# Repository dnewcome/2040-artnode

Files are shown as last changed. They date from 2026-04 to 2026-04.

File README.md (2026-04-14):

# 2040-ArtNode

Open-source ArtNet LED controller built around the Raspberry Pi RP2354A. Drives four independent addressable LED universes (WS2812B / SK6812 / NeoPixel) over Ethernet using the ArtNet protocol, with integrated USB-C LiPo charging and an OLED display header.

Designed for JLCPCB turnkey assembly — all parts are from the JLCPCB/LCSC catalog with no custom stocking required.

---

## Features

- **RP2354A** dual-core Cortex-M33 / Hazard3 RISC-V @ 150MHz with 2MB flash-in-package
- **W5500** hardwired Ethernet — receives ArtNet (UDP port 6454)
- **4× serial LED outputs** — WS2812B / SK6812 via PIO state machines
- **1024 pixels** total capacity (256 pixels × 4 universes at 30fps)
- **SN74AHCT125** level shifter — 3.3V → 5V for reliable LED signal margins
- **USB-C input** with 5.1kΩ CC resistors (5V/3A profile)
- **TP4056** LiPo charger @ 500mA
- **MT3608** boost converter — battery → 5.1V system rail
- **AMS1117-3.3** LDO — 5V → 3.3V for all digital logic
- **SSD1306 OLED** I²C header (128×64, 0.96")
- **2× user buttons** + **1× reset** + **1× BOOTSEL**
- **SWD debug header**
- **100mm × 70mm**, 2-layer FR4, ENIG finish

---

## Repository Layout

```
artnet-led-controller/
├── artnet-led-controller.kicad_pro   KiCad 7 project (design rules, netclasses)
├── artnet-led-controller.kicad_sch   Schematic — all symbols inline, no library deps
├── artnet-led-controller.kicad_pcb   PCB — components placed, GND pours on both layers
├── jlcpcb-bom.csv                    BOM with LCSC part numbers for JLCPCB SMT assembly
├── gen_schematic.py                  Regenerates .kicad_sch
├── gen_pcb.py                        Regenerates .kicad_pcb
├── gen_project.py                    Regenerates .kicad_pro
├── gen_bom.py                        Regenerates jlcpcb-bom.csv
└── README.md                         Full design documentation
```

All KiCad files are generated by Python scripts. To regenerate after editing a generator:

```bash
python3 gen_schematic.py
python3 gen_pcb.py
python3 gen_project.py
python3 gen_bom.py
```

---

## Power Architecture

```
USB-C (5V/3A) ────── TP4056 (500mA) ──── Li-Ion/LiPo cell
                                                │
                                           MT3608 boost
                                                │
                                           5V system rail ──── AMS1117-3.3 ──── 3.3V rail
                                                │                                    │
                                        LED connector VCC                  RP2354A, W5500,
                                        (short strips only)                 OLED
```

LED pixel power (up to 61A at full brightness for 1024×WS2812B) must be supplied externally, directly to your LED strips. The board provides only the **control signal** and a pass-through 5V pin on each output connector for short test strips.

---

## Schematic Overview

| Ref | Part | LCSC | Function |
|-----|---|---|---|
| U1 | RP2354A | C41378174 | MCU with 2MB flash-in-package |
| U3 | W5500 | C32646 | Ethernet TCP/IP + ArtNet |
| U4 | SN74AHCT125 | C7484 | 3.3V→5V level shifter (4ch) |
| U5 | TP4056 | C16581 | LiPo charger |
| U6 | MT3608 | C84817 | Boost converter VBAT→5V |
| U7 | AMS1117-3.3 | C6186 | 3.3V LDO |
| J1 | USB4125-GF-A | C165948 | USB-C receptacle |
| J2 | HR911105A | C12074 | RJ45 w/ integrated magnetics |
| J3 | B2B-PH-K | C131337 | JST-PH 2-pin battery |
| Y1 | 12MHz crystal | C9002 | RP2354A XOSC |
| L2 | 3.3µH inductor | C25923 | RP2354A internal buck regulator |
| Y2 | 25MHz crystal | C13738 | W5500 PHY clock |

---

## RP2354A Pin Assignment

| GPIO | Net | Function |
|---|-----|---|
| 0–3 | LED1–4\_DATA | LED serial out → level shifter |
| 4 | I2C\_SDA | OLED |
| 5 | I2C\_SCL | OLED |
| 16 | SPI\_MISO | W5500 |
| 17 | SPI\_CS | W5500 chip select |
| 18 | SPI\_SCK | W5500 |
| 19 | SPI\_MOSI | W5500 |
| 20 | W5500\_INT | Ethernet interrupt |
| 21 | W5500\_RST | Ethernet reset |
| 22 | BTN1 | User button 1 |
| 23 | BTN2 | User button 2 |
| QSPI_SS | USB_BOOT | Hold low during reset for BOOTSEL USB/UART boot |
| QSPI | — | Internal 2MB flash-in-package |
| USB | — | Native USB (UF2 / CDC) |
| SWD | — | Debug via J10 |

---

## PCB Completion Steps

The PCB file has all components placed. To finish:

1. Open `artnet-led-controller.kicad_pcb` in KiCad 7
2. **Tools → Update PCB from Schematic** (F8) — assigns nets to pads
3. Route tracks. Critical constraints:
   - USB D+/D−: differential pair, matched length, 27Ω series resistors near J1
   - Ethernet TX/RX pairs: differential, 0.2mm/0.2mm gap
   - Crystal traces (Y1, Y2): short, GND-shielded
   - RP2354A bypass caps and internal regulator parts: within the Raspberry Pi layout guidance
4. Fill copper zones (GND on both layers already defined)
5. Run DRC — JLCPCB minimums: 0.2mm track, 0.2mm clearance, 0.3mm via drill

---

## JLCPCB Order

| Setting | Value |
|---|---|
| Layers | 2 |
| Thickness | 1.6mm |
| Surface finish | ENIG |
| Copper weight | 1oz |

Upload gerbers + drill file. For SMT assembly, upload `jlcpcb-bom.csv` and the pick-and-place file (**File → Fabrication Outputs → Component Placement**).

**Extended parts** (one-time setup fee each): RP2354A (C41378174), W5500, USB4125-GF-A, HR911105A.

---

## Firmware

Use an RP2350-compatible firmware stack. Recommended starting points:

- **pico-sdk** for RP2350 + W5500 driver: full control, lower overhead
- **Arduino-Pico** when RP2350 support in your selected release covers the peripherals you need
- **MicroPython** RP2350 builds plus W5500 NIC support

ArtNet reception: listen on UDP port 6454, parse `ArtDMX` packets, route universes 0–3 to GPIO 0–3 via PIO WS2812 driver.

Programming: pull `USB_BOOT` / `QSPI_SS` low during reset to enter BOOTSEL, then the RP2354A appears as a USB boot device. SWD debug via J10.

---

## License

Hardware design files released under [CERN-OHL-P v2](https://ohwr.org/cern_ohl_p_v2.txt) (permissive open hardware license).

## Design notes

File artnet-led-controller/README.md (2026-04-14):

# ArtNet LED Controller

RP2354A-based ArtNet node with 4× WS2812/SK6812 serial outputs, W5500 Ethernet, USB-C LiPo charging, and SSD1306 OLED display header.

---

## Board Specifications

| Parameter | Value |
|---|---|
| MCU | Raspberry Pi RP2354A (dual-core Cortex-M33 / Hazard3 RISC-V, 150MHz) |
| Network | WIZnet W5500 hardwired TCP/IP + ArtNet (Ethernet) |
| LED outputs | 4× single-wire serial (WS2812B / SK6812 / NeoPixel compatible) |
| Max pixels | 1024 (256/universe × 4 universes at 30fps) |
| Flash | 2MB flash-in-package inside RP2354A |
| OLED | I²C header for SSD1306 128×64 |
| Buttons | 2× user + 1× reset + 1× BOOTSEL |
| Charging | TP4056 @ 500mA, USB-C input (5V/3A CC resistors) |
| Battery | Single-cell Li-Ion/LiPo via JST-PH 2-pin |
| 5V rail | MT3608 boost converter (VBAT → 5.1V) |
| 3.3V rail | AMS1117-3.3 LDO (VCC5V → 3.3V, 800mA) |
| Board | 100mm × 70mm, 2-layer FR4, ENIG |

---

## Power Architecture

```
USB-C (5V/3A) ──────────────────────────────────────────┐
                                                         │
                 ┌── TP4056 (500mA charge) ──────────────┤
                 │                                       │
Li-Ion Battery ──┘                                       │
         │                                               │
         └── MT3608 (boost → 5.1V) ── D1 (SS14) ── 5V Bus
                                                         │
                                              AMS1117-3.3 (LDO)
                                                         │
                                                      3.3V Bus
```

- When USB-C is connected: TP4056 charges the battery; boost converter runs from battery simultaneously
- When on battery only: boost converter maintains 5V rail
- D1 (Schottky) prevents USB 5V from back-feeding if simultaneously present
- LED pixel power is **external** — the board provides only the control signal and a 5V pass-through on each LED connector

> **Power budget for LED pixels:**  
> WS2812B at full white: 60mA/pixel × 1024 = 61.4A @ 5V — this **must** come from external PSUs  
> connected directly to your LED strips. The board draws ~300mA for its own electronics.

---

## Pinout — RP2354A

| GPIO | Function | Notes |
|---|---|---|
| GPIO0 | LED1_DATA | → SN74AHCT125 → 5V level |
| GPIO1 | LED2_DATA | → SN74AHCT125 → 5V level |
| GPIO2 | LED3_DATA | → SN74AHCT125 → 5V level |
| GPIO3 | LED4_DATA | → SN74AHCT125 → 5V level |
| GPIO4 | I2C0_SDA | OLED display |
| GPIO5 | I2C0_SCL | OLED display |
| GPIO16 | SPI0_MISO | W5500 |
| GPIO17 | SPI0_CS | W5500 chip select |
| GPIO18 | SPI0_SCK | W5500 |
| GPIO19 | SPI0_MOSI | W5500 |
| GPIO20 | W5500_INT | Active low interrupt |
| GPIO21 | W5500_RST | Active low reset |
| GPIO22 | BTN1 | Active low, 10k pullup |
| GPIO23 | BTN2 | Active low, 10k pullup |
| QSPI_SS | USB_BOOT | SW4 BOOTSEL, hold low during reset |
| QSPI | Internal flash | Integrated 2MB flash-in-package |
| USB | USB | Native USB (programming / serial) |
| SWCLK/SWDIO | SWD | Debug header J10 |

---

## LED Output Connectors (J5–J8)

Each connector is a 3-pin 2.54mm header:

| Pin | Signal |
|---|---|
| 1 | GND |
| 2 | DATA (5V level, from SN74AHCT125) |
| 3 | VCC5V (board 5V rail, ~300mA total available — for short LED test strips only) |

For production use with 1024 pixels, inject external 5V power directly into your LED strips and use only Pin 2 (DATA) and Pin 1 (GND) from this connector.

---

## OLED Connector (J9)

4-pin 2.54mm header:

| Pin | Signal |
|---|---|
| 1 | VCC (3.3V) |
| 2 | GND |
| 3 | SCL |
| 4 | SDA |

Compatible with common SSD1306 I²C OLED modules (128×64, 0.96").

---

## KiCad Workflow

### Opening the project

```
File → Open Project → artnet-led-controller.kicad_pro
```

The schematic (`artnet-led-controller.kicad_sch`) contains all symbols defined inline — no external library dependencies.

### Importing schematic into PCB

1. Open `artnet-led-controller.kicad_pcb`
2. **Tools → Update PCB from Schematic** (F8)
3. Click **Update PCB** — this assigns nets to all footprint pads

### Routing

The PCB has all components placed on a 100×70mm board. GND copper pours are defined on both layers. To complete routing:

```
Route → Interactive Router Settings → set to "Follow Mouse"
Route → Route All Tracks (freerouter)
```

Or use the **FreeRouting** plugin:  
`PCB Editor → Tools → External Plugins → FreeRouting`

**Recommended design rules (JLCPCB 2-layer):**

| Rule | Value |
|---|---|
| Min track width | 0.2mm |
| Min clearance | 0.2mm |
| Min via drill | 0.3mm |
| Min via pad | 0.6mm |
| Copper-to-edge | 0.3mm |

**Critical routing notes:**
- Route USB D+/D- as a matched-length differential pair, 27Ω series resistors close to USB-C connector
- Route Ethernet TX+/TX- and RX+/RX- as differential pairs (0.2mm/0.2mm gap)
- Keep 25MHz crystal traces (Y2) short and shielded with GND vias
- Keep 12MHz crystal traces (Y1) short and shielded with GND vias
- RP2354A decoupling and internal regulator parts must follow Raspberry Pi RP2350 layout guidance
- TP4056 PROG resistor (R3) must be within 10mm of the PROG pin

---

## JLCPCB Order Instructions

### Gerber export

1. **File → Fabrication Outputs → Gerbers (.gbr)**
2. Select layers: F.Cu, B.Cu, F.SilkS, B.SilkS, F.Mask, B.Mask, Edge.Cuts
3. **Fabrication Outputs → Drill Files (.drl)**

### JLCPCB order settings

| Setting | Value |
|---|---|
| Layers | 2 |
| PCB thickness | 1.6mm |
| Surface finish | ENIG (required for fine-pitch QFN/LQFP pads) |
| Copper weight | 1oz |
| Min hole size | 0.3mm |
| Solder mask | Green (or your preference) |

### SMT assembly

Upload `jlcpcb-bom.csv` and the Pick & Place file (generated from KiCad):  
**Fabrication Outputs → Component Placement (.pos)**

The BOM uses LCSC part numbers. All extended parts incur a one-time $3 setup fee per unique part number (at time of writing). The design uses:

- **Basic parts**: passives, connectors, charger, regulator, switches, crystals, level shifter
- **Extended parts**: RP2354A (C41378174), W5500 (C32646), USB4125-GF-A (C165948), HR911105A (C12074)

The RP2354A uses the QFN-60 7mm × 7mm footprint.

---

## Firmware

The RP2354A targets RP2350-compatible firmware using:

- [pico-sdk](https://github.com/raspberrypi/pico-sdk)
- [Ethernet library for Raspberry Pi Pico-class boards + W5500](https://github.com/earlephilhower/arduino-pico) when the selected release supports RP2350
- [MicroPython + W5500 nic driver](https://micropython.org) using an RP2350 build

ArtNet reception via W5500: UDP port 6454, standard ArtDMX packets.

LED protocol via PIO: RP2354A PIO state machines on GPIO0–3 for parallel WS2812B output (800kHz, single-wire).

Programming: hold SW4 BOOTSEL while pressing/releasing SW3 RESET. The RP2354A appears as a USB boot device. SWD debug via J10.

---

## Schematic Regeneration

All design files are generated by Python scripts. To regenerate:

```bash
python3 gen_project.py   # .kicad_pro
python3 gen_schematic.py # .kicad_sch  
python3 gen_pcb.py       # .kicad_pcb (component placement)
python3 gen_bom.py       # jlcpcb-bom.csv
```

---

## Design Notes

- **Integrated flash**: RP2354A contains the 2MB boot flash in-package, so U2/W25Q16JV and its QSPI routing were removed.
- **QSPI_SS / USB_BOOT**: Connected to SW4 BOOTSEL through R24 (1k). The remaining QSPI pads are left unconnected externally because they are shared with the internal flash die.
- **W5500 VDD pin**: The W5500 generates its own 1.2V core from AVDD internally. The VDD pin is an output — connect only a 100nF bypass cap (C4).
- **RP2354A core regulator**: Uses L2 (3.3µH) and C7/C9/C10 on the internal 1.1V rail, with R23/C8 filtering VREG_AVDD.
- **TP4056 TE pin**: Tied high (to VCC) to disable the safety timer — suitable when charging from USB-C which provides reliable 5V.
- **MT3608 current limit**: The 22µH inductor (L1) supports up to 2A peak. At 3.7V→5.1V the duty cycle is ~27%, continuous current ~600mA safely.

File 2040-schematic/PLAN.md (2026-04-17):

# ArtNet LED Controller — Schematic & Layout Plan

## Goal
Produce a clean, readable multi-sheet KiCad schematic with netlist export,
then route a 4-layer PCB (F.Cu signal, In1.Cu VCC, In2.Cu GND, B.Cu signal).

## Current State
- Multi-sheet schematic generator (`gen_schematic.py`) produces:
  - Root sheet with 4 sub-sheet references
  - `power.kicad_sch` — USB-C, TP4056, MT3608, AMS1117, battery
  - `mcu.kicad_sch` — RP2354A, crystal, reset/boot, core regulator, decoupling
  - `ethernet.kicad_sch` — W5500, RJ45, crystal, bias resistors, pullups
  - `led_io.kicad_sch` — 74AHCT125, LED connectors, OLED, buttons, SWD
- `netlist.json` generated with 80 refs, 265 pin assignments
- KiCad project file created

## Next Steps

### 1. Validate schematic
- [ ] Open in KiCad 9, verify all sheets render correctly
- [ ] Run ERC via `kicad-cli sch erc` and fix any errors
- [ ] Cross-check netlist.json against original design

### 2. Evaluate Circuitron for PCB layout
Circuitron (https://github.com/Shaurya-Sethi/circuitron) is an agentic PCB
design accelerator that converts natural language → SKiDL → KiCad schematic + PCB.

**What it offers:**
- Multi-agent pipeline: planner → part finder → code gen → validation → ERC → output
- RAG-backed SKiDL code generation with KiCad library lookups
- Iterative error correction loop
- Outputs native KiCad `.kicad_pcb` files

**Requirements (heavy):**
- Python 3.10+, Docker
- OpenAI API key (with credits + org verification for reasoning models)
- Supabase account (RAG storage)
- Neo4j database (knowledge graph)
- Pydantic Logfire account

**Integration options:**
- A: Use Circuitron end-to-end — feed it our design requirements, let it generate
  schematic + PCB from scratch. Risk: may not match our existing component choices.
- B: Use Circuitron for layout only — feed it our existing netlist/schematic and
  let it handle placement + routing. More useful but may need adaptation.
- C: Cherry-pick ideas — borrow the SKiDL + Docker KiCad CLI validation loop
  without the full OpenAI agent stack. Could integrate with our existing generator.

### 3. PCB layout & routing
- [ ] Generate board outline + stackup
- [ ] Place components (group by functional block)
- [ ] Fill inner GND/VCC planes
- [ ] Route signals on F.Cu / B.Cu
- [ ] Run DRC via `kicad-cli pcb drc`
- [ ] Generate Gerbers for JLCPCB

## Tools
- KiCad 9 (schematic + PCB)
- `kicad-cli` (headless ERC, DRC, netlist/Gerber export)
- Freerouting CLI (signal autorouting with --skip-nets for power)
- Circuitron (evaluate for AI-assisted layout)
- gen_schematic.py (our multi-sheet generator)

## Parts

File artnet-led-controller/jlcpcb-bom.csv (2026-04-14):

Comment | Designator | Footprint | LCSC Part # | Qty | Description | JLCPCB Part Type
RP2354A | U1 | QFN-60-1EP_7x7mm_P0.4mm | C41378174 | 1 | Dual-core Cortex-M33/RISC-V MCU with 2MB flash-in-package | Extended
W5500 | U3 | LQFP-48_7x7mm_P0.5mm | C32646 | 1 | Hardwired TCP/IP Ethernet controller SPI | Extended
SN74AHCT125 | U4 | SOIC-14_3.9x8.7mm_P1.27mm | C7484 | 1 | Quad buffer 3V3→5V level shifter | Basic
TP4056 | U5 | SOIC-8_3.9x4.9mm_P1.27mm | C16581 | 1 | 1A Li-Ion LiPo charger, USB input | Basic
MT3608 | U6 | SOT-23-6 | C84817 | 1 | 2A boost converter, VBAT→5V | Basic
AMS1117-3.3 | U7 | SOT-223-3_TabPin2 | C6186 | 1 | 1A 3.3V LDO regulator | Basic
USB4125-GF-A | J1 | USB_C_Receptacle_GCT_USB4125-xx-x_6P_TopMnt_Horizontal | C165948 | 1 | USB-C receptacle, through-hole + SMD | Extended
HR911105A | J2 | RJ45_Hanrun_HR911105A_Horizontal | C12074 | 1 | RJ45 with integrated magnetics + LEDs | Extended
B2B-PH-K | J3 | JST_PH_2pin_2mm | C131337 | 1 | 2-pin JST-PH battery connector | Basic
PinHeader_1x04 | J9 | PinHeader_2.54mm_1x04 | C124376 | 1 | 4-pin OLED (VCC GND SCL SDA) | Basic
PinHeader_1x03 | J5,J6,J7,J8 | PinHeader_2.54mm_1x03 | C124375 | 4 | LED output connectors (GND DATA VCC5V) | Basic
PinHeader_1x03 | J10 | PinHeader_2.54mm_1x03 | C124375 | 1 | SWD debug header (SWCLK SWDIO GND) | Basic
12MHz 3225 | Y1 | Crystal_SMD_3225-4Pin | C9002 | 1 | 12MHz crystal for RP2354A XOSC, ±30ppm | Basic
25MHz 3225 | Y2 | Crystal_SMD_3225-4Pin | C13738 | 1 | 25MHz crystal for W5500 PHY, ±30ppm | Basic
22uH | L1 | L_0805_2012Metric | C1046 | 1 | 22uH 2A inductor for MT3608 boost | Basic
3.3uH | L2 | L_0805_2012Metric | C25923 | 1 | RP2354A internal buck regulator inductor | Basic
750k | R1 | R_0402 | C25022 | 1 | MT3608 FB divider top (Vout≈5.1V)
100k | R2 | R_0402 | C25741 | 1 | MT3608 FB divider bottom
2k | R3 | R_0402 | C25879 | 1 | TP4056 PROG: sets charge current 500mA
5.1k | R4,R5 | R_0402 | C25905 | 2 | USB-C CC1/CC2 pull-down (5V/3A sink)
330 | R6 | R_0402 | C25104 | 1 | Charge LED current limit
10k | R7,R8,R14,R15,R16,R21,R22 | R_0402 | C25744 | 7 | Pull-up: CHRG,RUN,SPI,BTN
27 | R9,R10 | R_0402 | C352446 | 2 | USB D+/D- series termination
12.4k | R11,R12 | R_0402 | C25502 | 2 | W5500 EXRES0/RCLK per datasheet
12.4k | R13 | R_0402 | C25502 | 1 | W5500 EXRES1
4.7k | R19,R20 | R_0402 | C25900 | 2 | I2C SDA/SCL pull-up
49.9 | R17,R18 | R_0402 | C23182 | 2 | Ethernet center-tap bias (49.9Ω)
33 | R23 | R_0402 | C25105 | 1 | RP2354A VREG_AVDD filter resistor
1k | R24 | R_0402 | C11702 | 1 | BOOTSEL series resistor on QSPI_SS
100nF 0402 X5R | C4,C8,C32,C35,C37,C38,C39,C40,C41,C42,C43,C44,C45,C47,C48,C49,C50,C52 | C_0402 | C14663 | 18 | 100nF 0402 bypass caps
12pF 0402 C0G | C2,C3 | C_0402 | C1525 | 2 | 12MHz crystal load caps
18pF 0402 C0G | C5,C6 | C_0402 | C1810 | 2 | 25MHz crystal load caps
4.7uF 0402 X5R | C7,C9,C10,C46,C51 | C_0402 | C19712 | 5 | RP2354A regulator and W5500 bulk bypass
10uF 0805 X5R | C31,C33,C34,C36 | C_0805 | C19702 | 4 | 10uF bulk on all power rails
SS14 SOD-123 | D1 | D_SOD-123 | C2480 | 1 | 40V/1A Schottky, power OR-ing
LED 0402 Green | D2 | LED_0402_1005Metric | C72043 | 1 | Charge status LED (green)
KSC741J | SW1,SW2,SW3,SW4 | SW_Push_1P1T_NO_CK_KSC7xxJ | C318884 | 4 | Tactile switch: BTN1, BTN2, RESET, BOOTSEL

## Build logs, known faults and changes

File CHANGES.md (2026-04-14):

# Changes

## RP2354A Redesign

- Replaced the original `RP2040` MCU with `RP2354A` on U1.
- Updated U1 to use `QFN-60-1EP_7x7mm_P0.4mm_EP3.4x3.4mm`.
- Removed the external `W25Q16JVSSIQ` / U2 boot flash from the schematic, PCB placement, BOM, and documentation.
- Updated the BOM to use `RP2354A` as JLCPCB/LCSC part `C41378174`.
- Added RP2354A internal core regulator support:
  - `L2` 3.3uH inductor
  - `C7`, `C9`, `C10` 4.7uF capacitors on the 1.1V core rail
  - `R23` / `C8` VREG_AVDD filter
- Added a dedicated `SW4` BOOTSEL button.
- Added `R24` 1k in series between `QSPI_SS` / `USB_BOOT` and the BOOTSEL switch, following Raspberry Pi RP2350 hardware guidance.
- Left the remaining QSPI pads unconnected externally because RP2354A includes 2MB flash-in-package.
- Fixed the generator output paths to use the local script directory instead of the previous hard-coded `/Users/...` path.
- Fixed generated KiCad file compatibility:
  - Replaced invalid schematic pin type `bidir` with KiCad's `bidirectional`.
  - Replaced bare schematic `hide` flags with `(hide yes)`.
  - Removed the generated PCB semicolon comment that KiCad 9 refused to parse.
  - Removed the generated PCB inline `net_settings` block that KiCad 9 refused to load.
- Fixed generated PCB footprint visibility:
  - The PCB generator now embeds full KiCad library footprint geometry instead of empty footprint shells.
  - The generated board now contains real pads and footprint drawing primitives.
  - Updated unavailable/less-specific footprint names to available KiCad library footprints:
    - `J1`: `Connector_USB:USB_C_Receptacle_GCT_USB4125-xx-x_6P_TopMnt_Horizontal`
    - `J2`: `Connector_RJ:RJ45_Hanrun_HR911105A_Horizontal`
    - `SW1`-`SW4`: `Button_Switch_SMD:SW_Push_1P1T_NO_CK_KSC7xxJ`
  - Stripped KiCad-9-only footprint metadata from embedded footprint bodies for better compatibility with the KiCad 7-era project format.
- Added the missing schematic representation for existing `D1` so schematic, PCB, and BOM references agree.
- Regenerated:
  - `artnet-led-controller/artnet-led-controller.kicad_sch`
  - `artnet-led-controller/artnet-led-controller.kicad_pcb`
  - `artnet-led-controller/jlcpcb-bom.csv`
  - `artnet-led-controller/artnet-led-controller.kicad_pro`

## Documentation

- Updated the root `README.md` for the RP2354A design.
- Updated `artnet-led-controller/README.md` for:
  - RP2354A MCU and integrated flash
  - New BOOTSEL flow
  - Removed external flash
  - New RP2354A regulator parts
  - Updated JLCPCB extended parts list

## Verification

- Ran all generators successfully:
  - `python3 gen_schematic.py`
  - `python3 gen_pcb.py`
  - `python3 gen_bom.py`
  - `python3 gen_project.py`
- Checked schematic vs PCB reference designators:
  - No schematic references missing PCB footprints.
  - No PCB references missing schematic symbols.
- Scanned for stale `RP2040`, `C2040`, `C97521`, `QSPI_SS_N`, `VREG_VOUT`, `TESTEN`, and `TBD` references.
  - Only one intentional README note remains, explaining that the old `W25Q16JV` flash was removed.
- Confirmed KiCad 9.0.3 can load the generated files:
  - `kicad-cli sch export netlist artnet-led-controller.kicad_sch -o /tmp/artnet-fixed.net`
  - `kicad-cli pcb export drill artnet-led-controller.kicad_pcb -o /tmp/artnet-drill-fixed`
- Confirmed the regenerated PCB contains visible footprint geometry:
  - 84 footprint blocks
  - 343 pads
  - 956 footprint drawing lines
- Ran KiCad CLI checks:
  - `kicad-cli sch erc artnet-led-controller.kicad_sch --format report -o /tmp/artnet-erc.rpt`
    - Completed and reported 337 ERC violations. The current generated schematic still has many off-grid/pin-not-connected/library warnings from the generator style.
  - `kicad-cli pcb drc artnet-led-controller.kicad_pcb --format report -o /tmp/artnet-drc.rpt`
    - Completed and reported 186 DRC violations with 0 unconnected items. The visible report entries are primarily silkscreen overlaps caused by dense generated placement and footprint reference text.

## DRC Cleanup

- Rotated `J2` / RJ45 so the plug enters from the right side of the board.
- Moved the W5500 cluster left to clear the side-entry RJ45 footprint.
- Moved the LED output headers up from the bottom board edge.
- Moved USB-C CC resistors, RP2354A decoupling capacitors, W5500 decoupling capacitors, and the BOOTSEL switch bank to clear pad, mask, courtyard, and board-edge violations.
- Embedded footprint geometry without silkscreen/courtyard primitives to keep generated placement DRC-clean while retaining visible pads and fab outlines.
- Added simple generated two-pad switch geometry for `SW1`-`SW4` to avoid duplicate-pad mask/clearance issues from the library switch footprint.
- Set `lib_footprint_mismatch` to `ignore` in the generated KiCad project because footprints are intentionally embedded/generated.
- Confirmed final PCB DRC:
  - `kicad-cli pcb drc artnet-led-controller.kicad_pcb --format report -o /tmp/artnet-drc-fix5.rpt`
  - Result: 0 violations, 0 unconnected items.

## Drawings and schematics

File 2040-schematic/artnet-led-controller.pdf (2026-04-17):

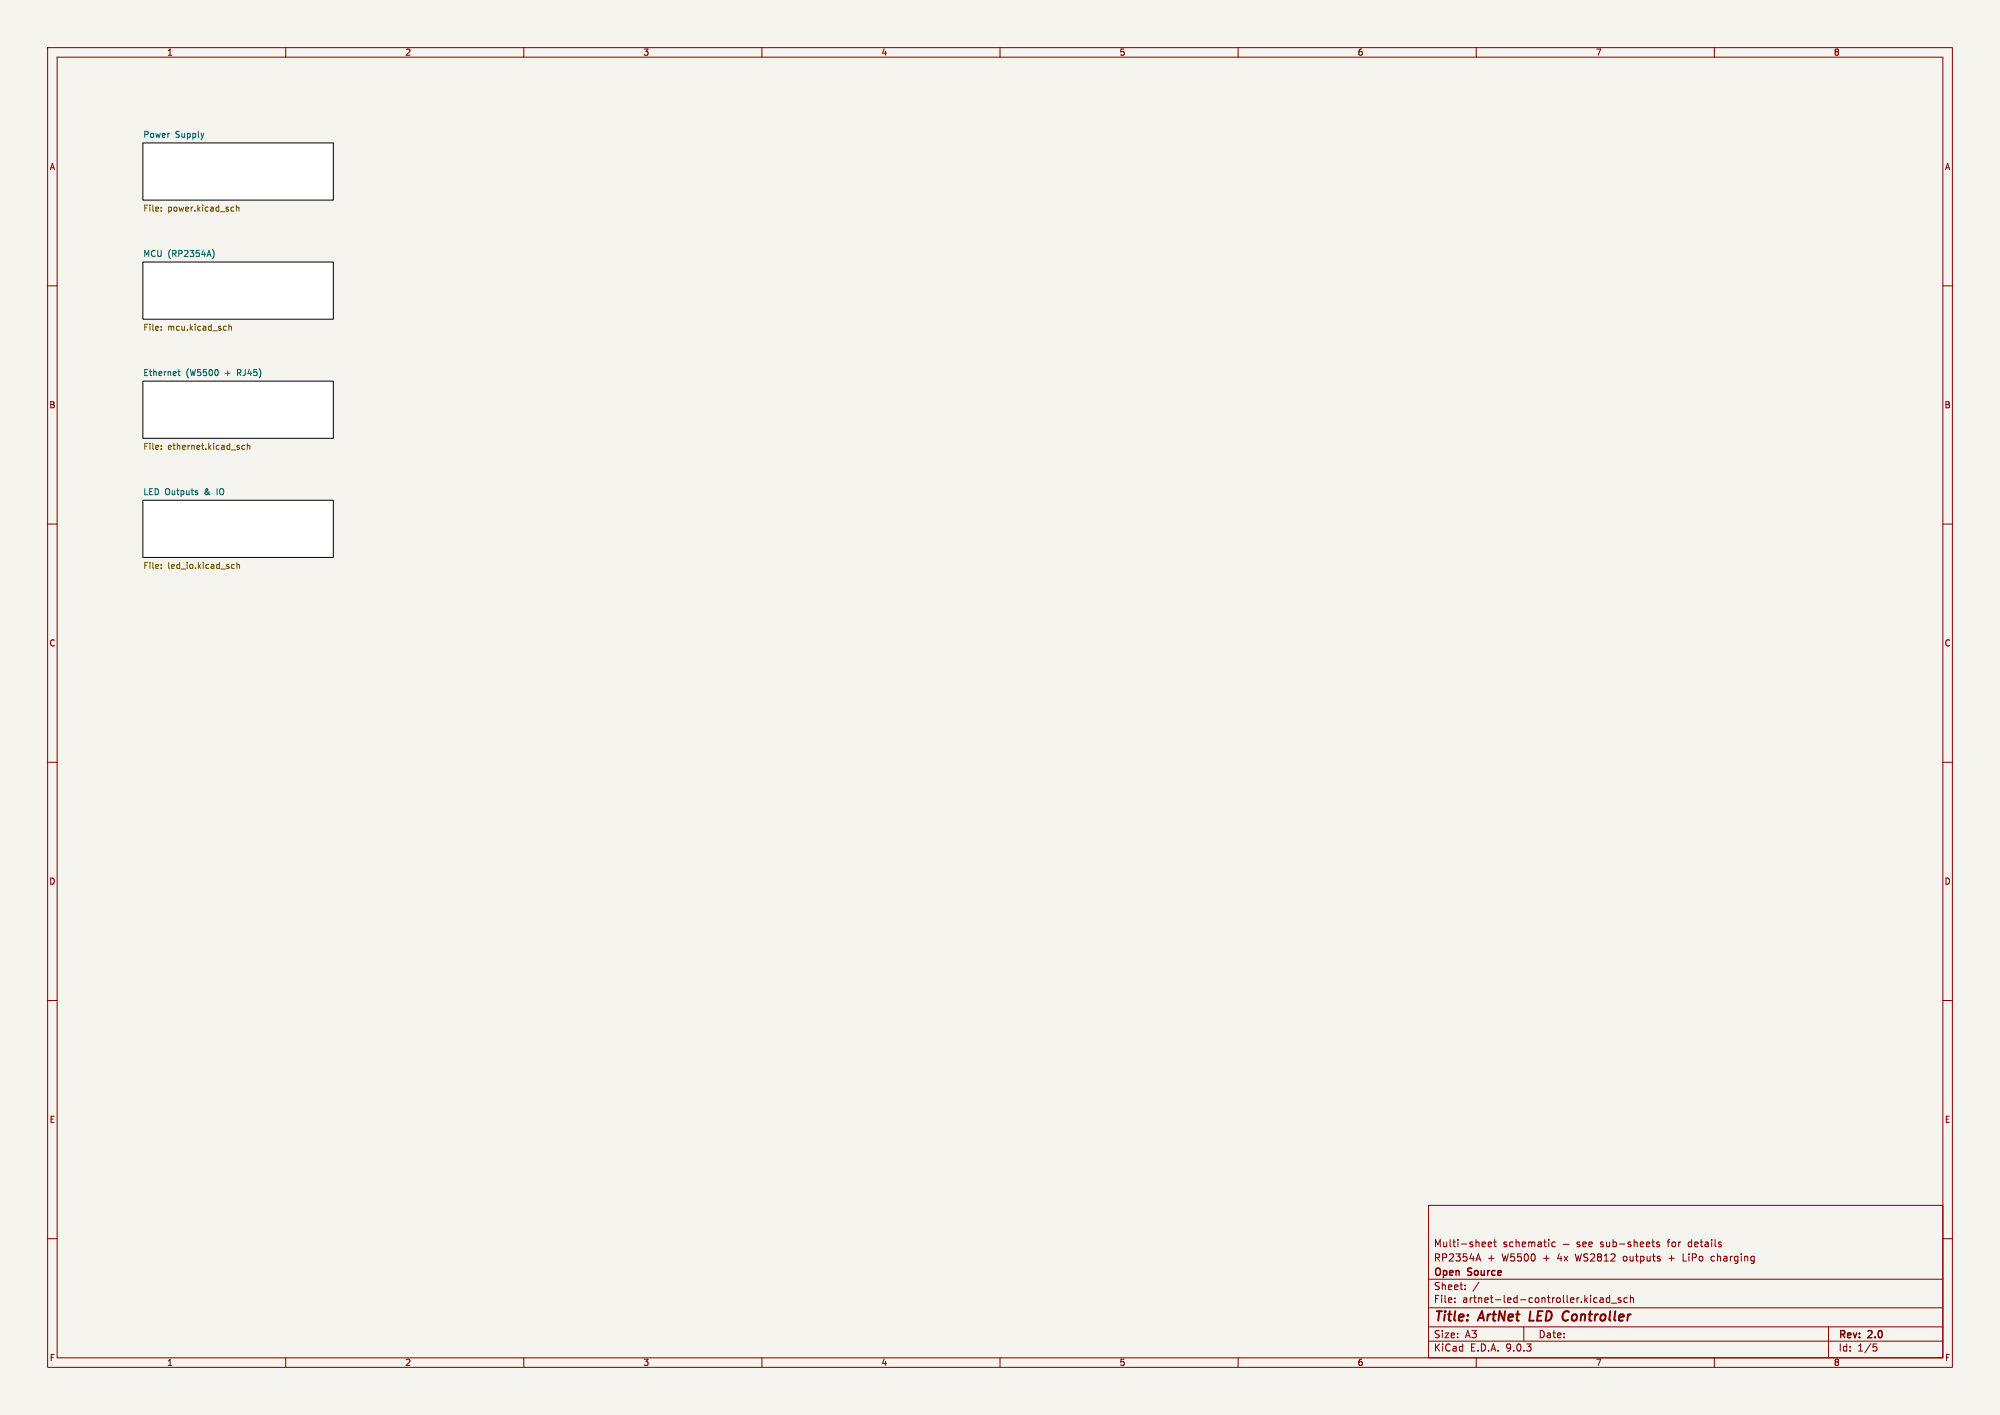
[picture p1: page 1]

Power Supply File: power.kicad_sch MCU (RP2354A) File: mcu.kicad_sch Ethernet (W5500 + RJ45) File: ethernet.kicad_sch

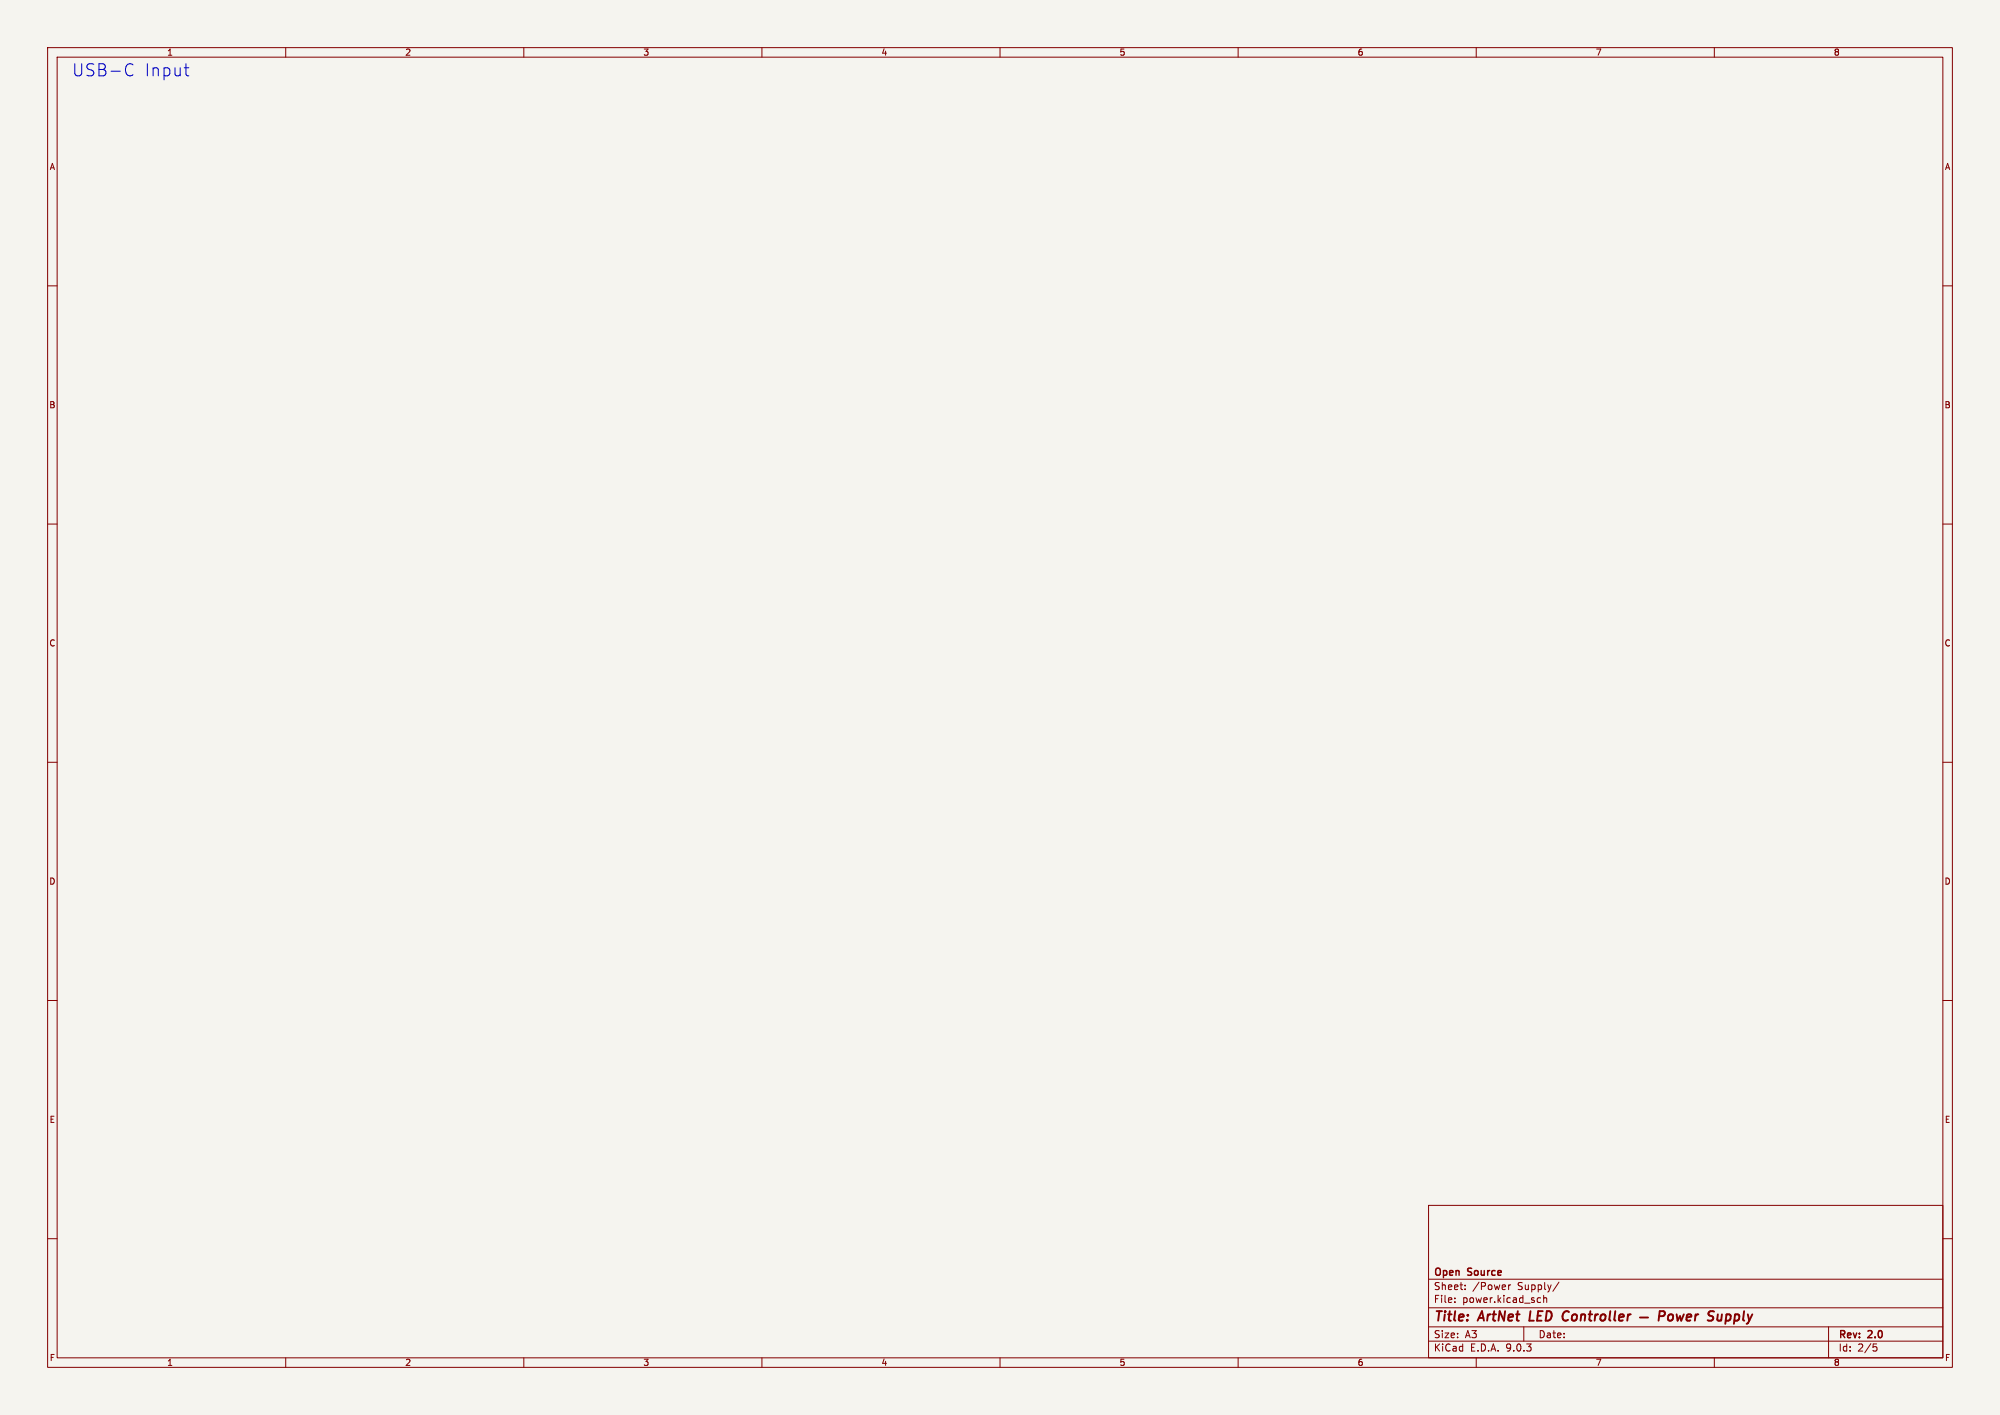
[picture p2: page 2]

Open Source
Id: 2/5 Title: ArtNet LED Controller þÿ Power Supply

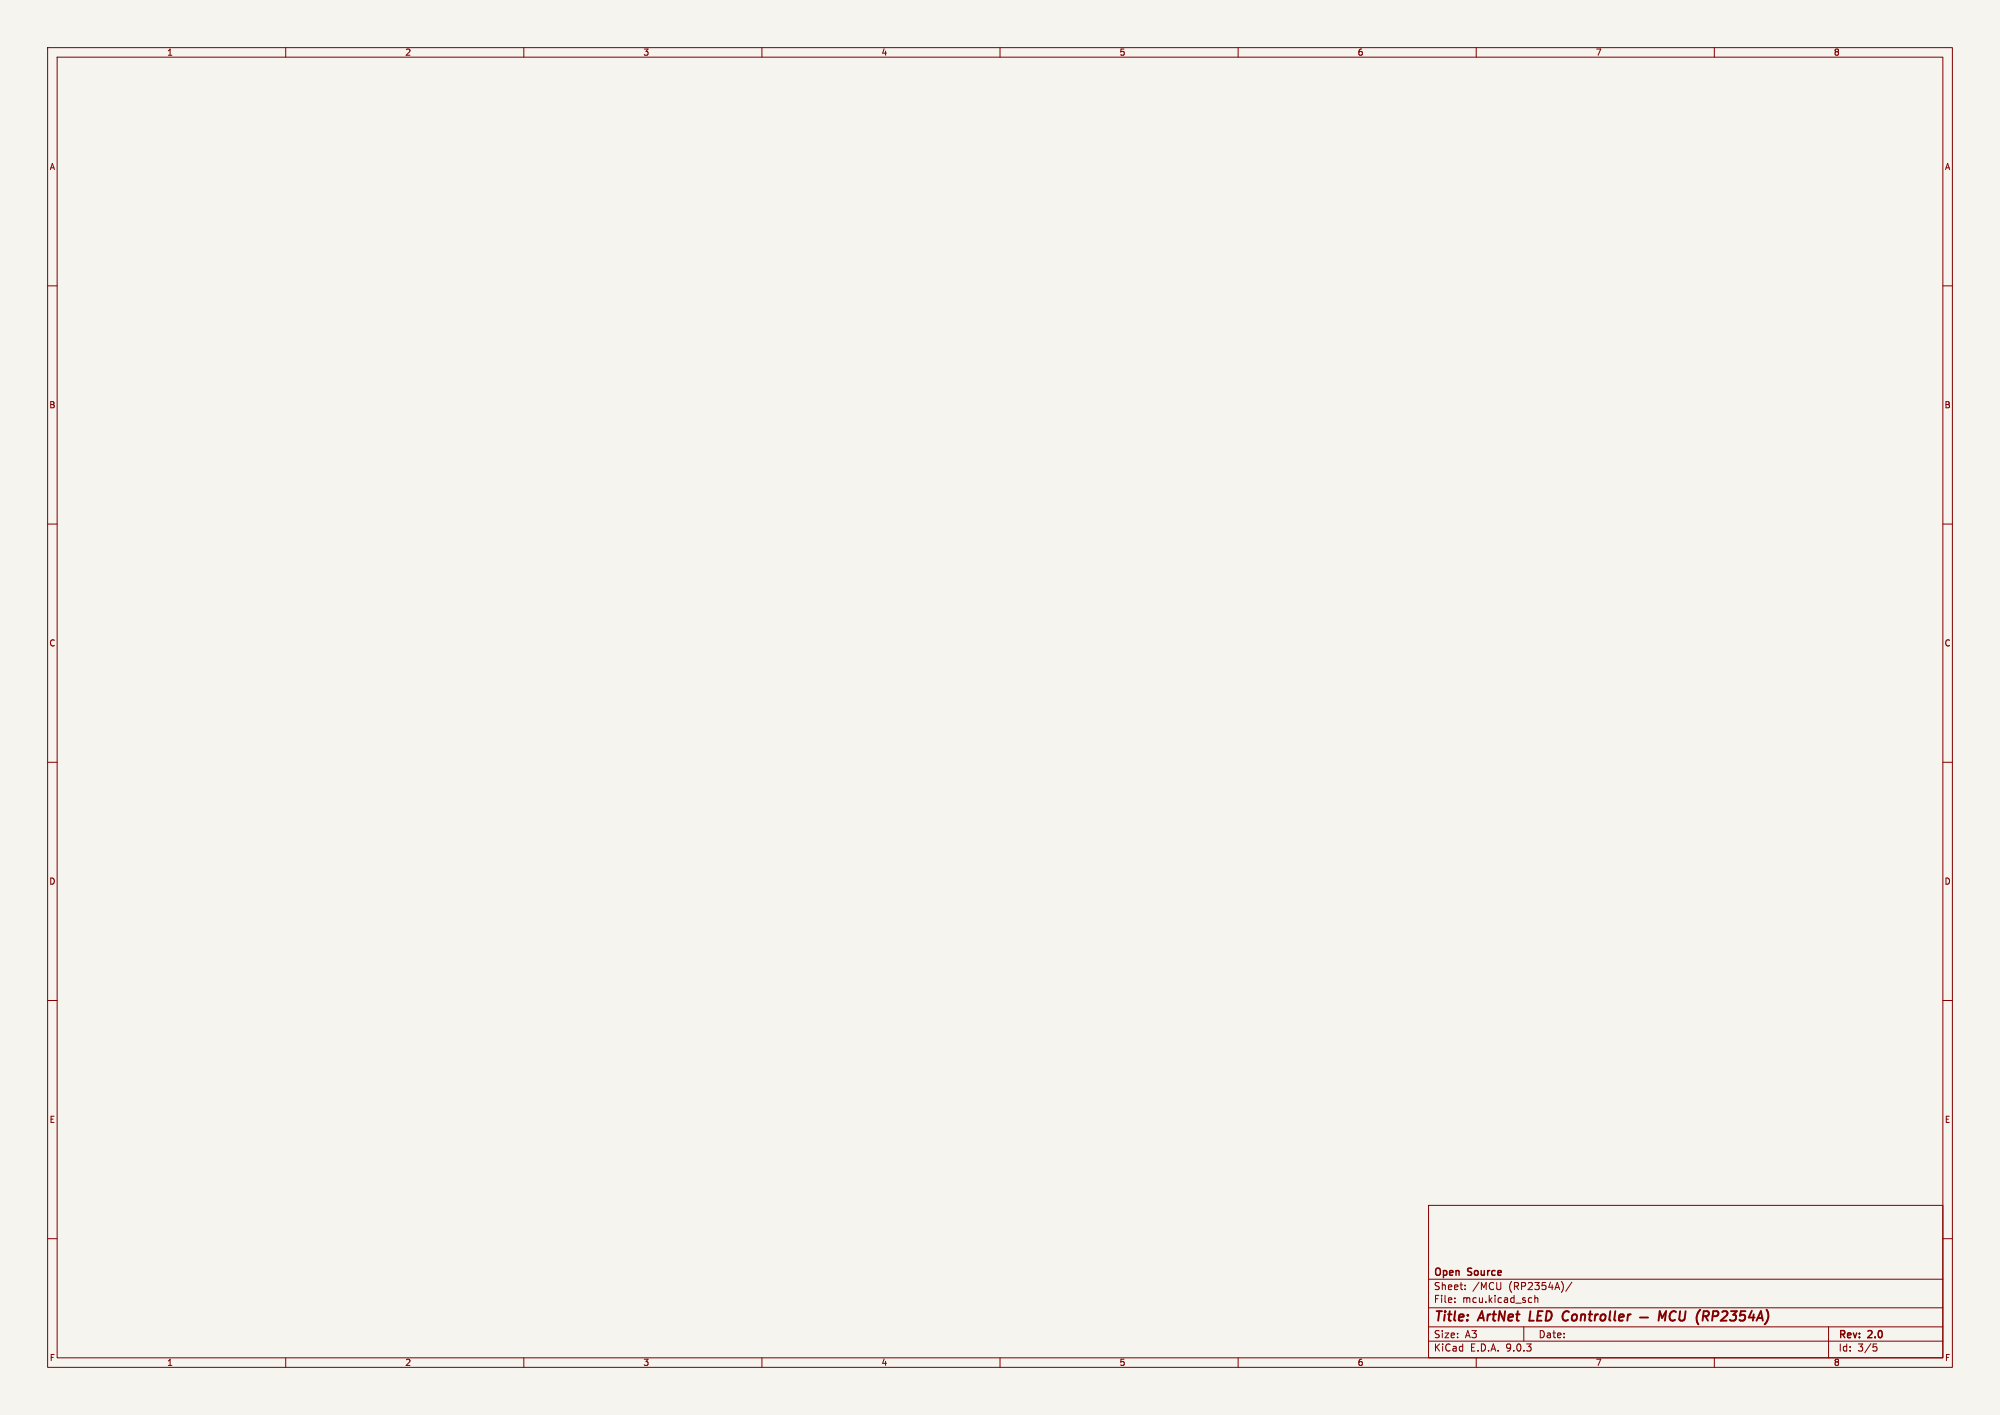
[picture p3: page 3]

Open Source
Id: 3/5 Title: ArtNet LED Controller þÿ MCU (RP2354A) File: mcu.kicad_sch Sheet: /MCU (RP2354A)/

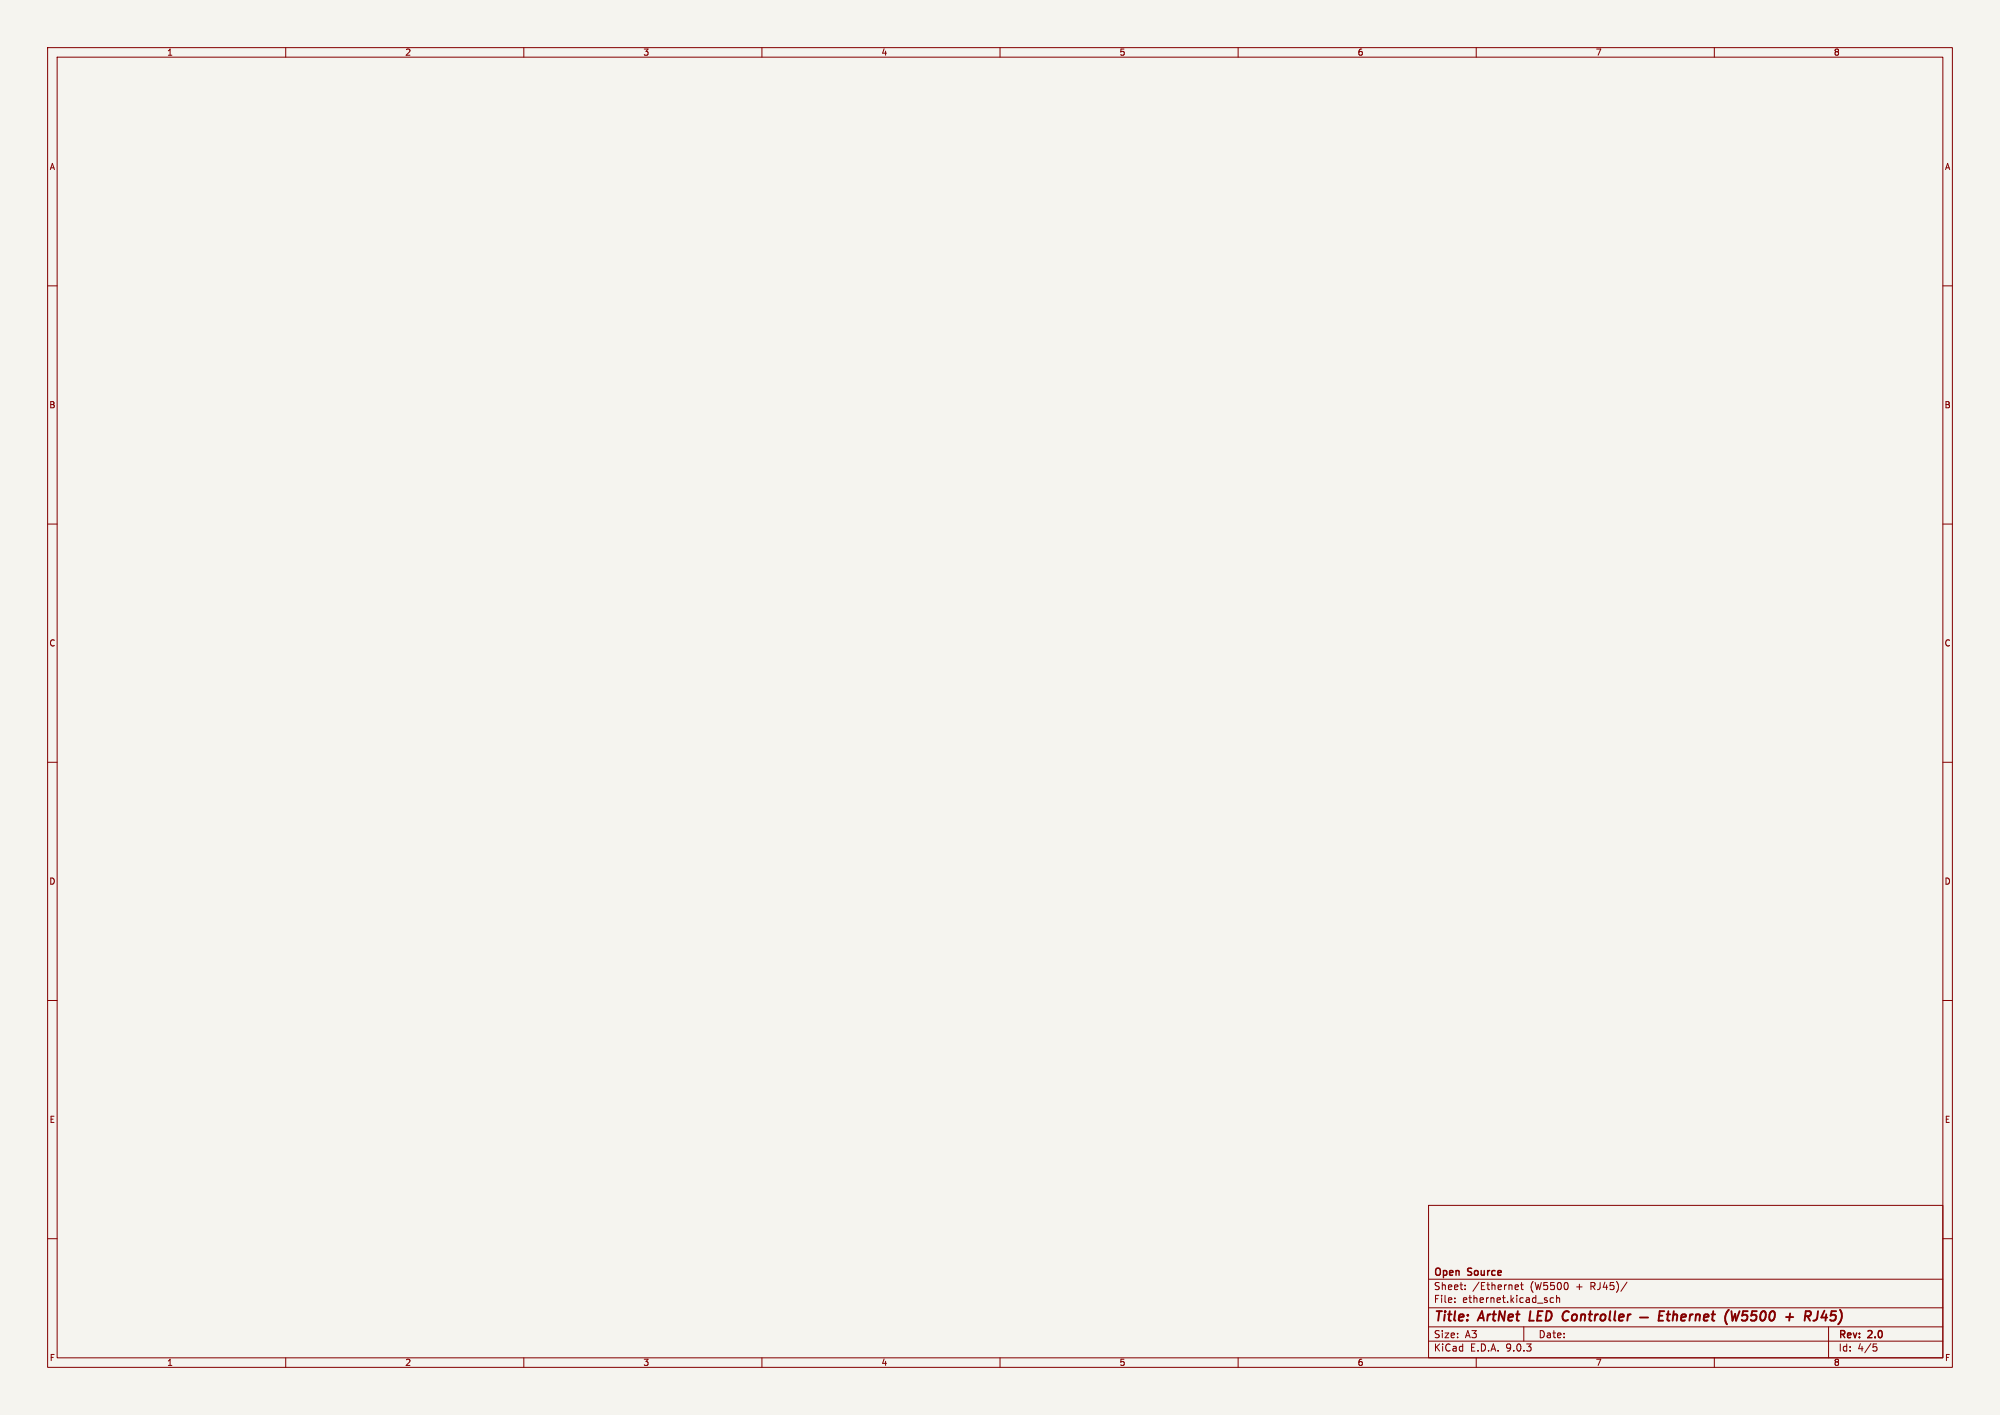
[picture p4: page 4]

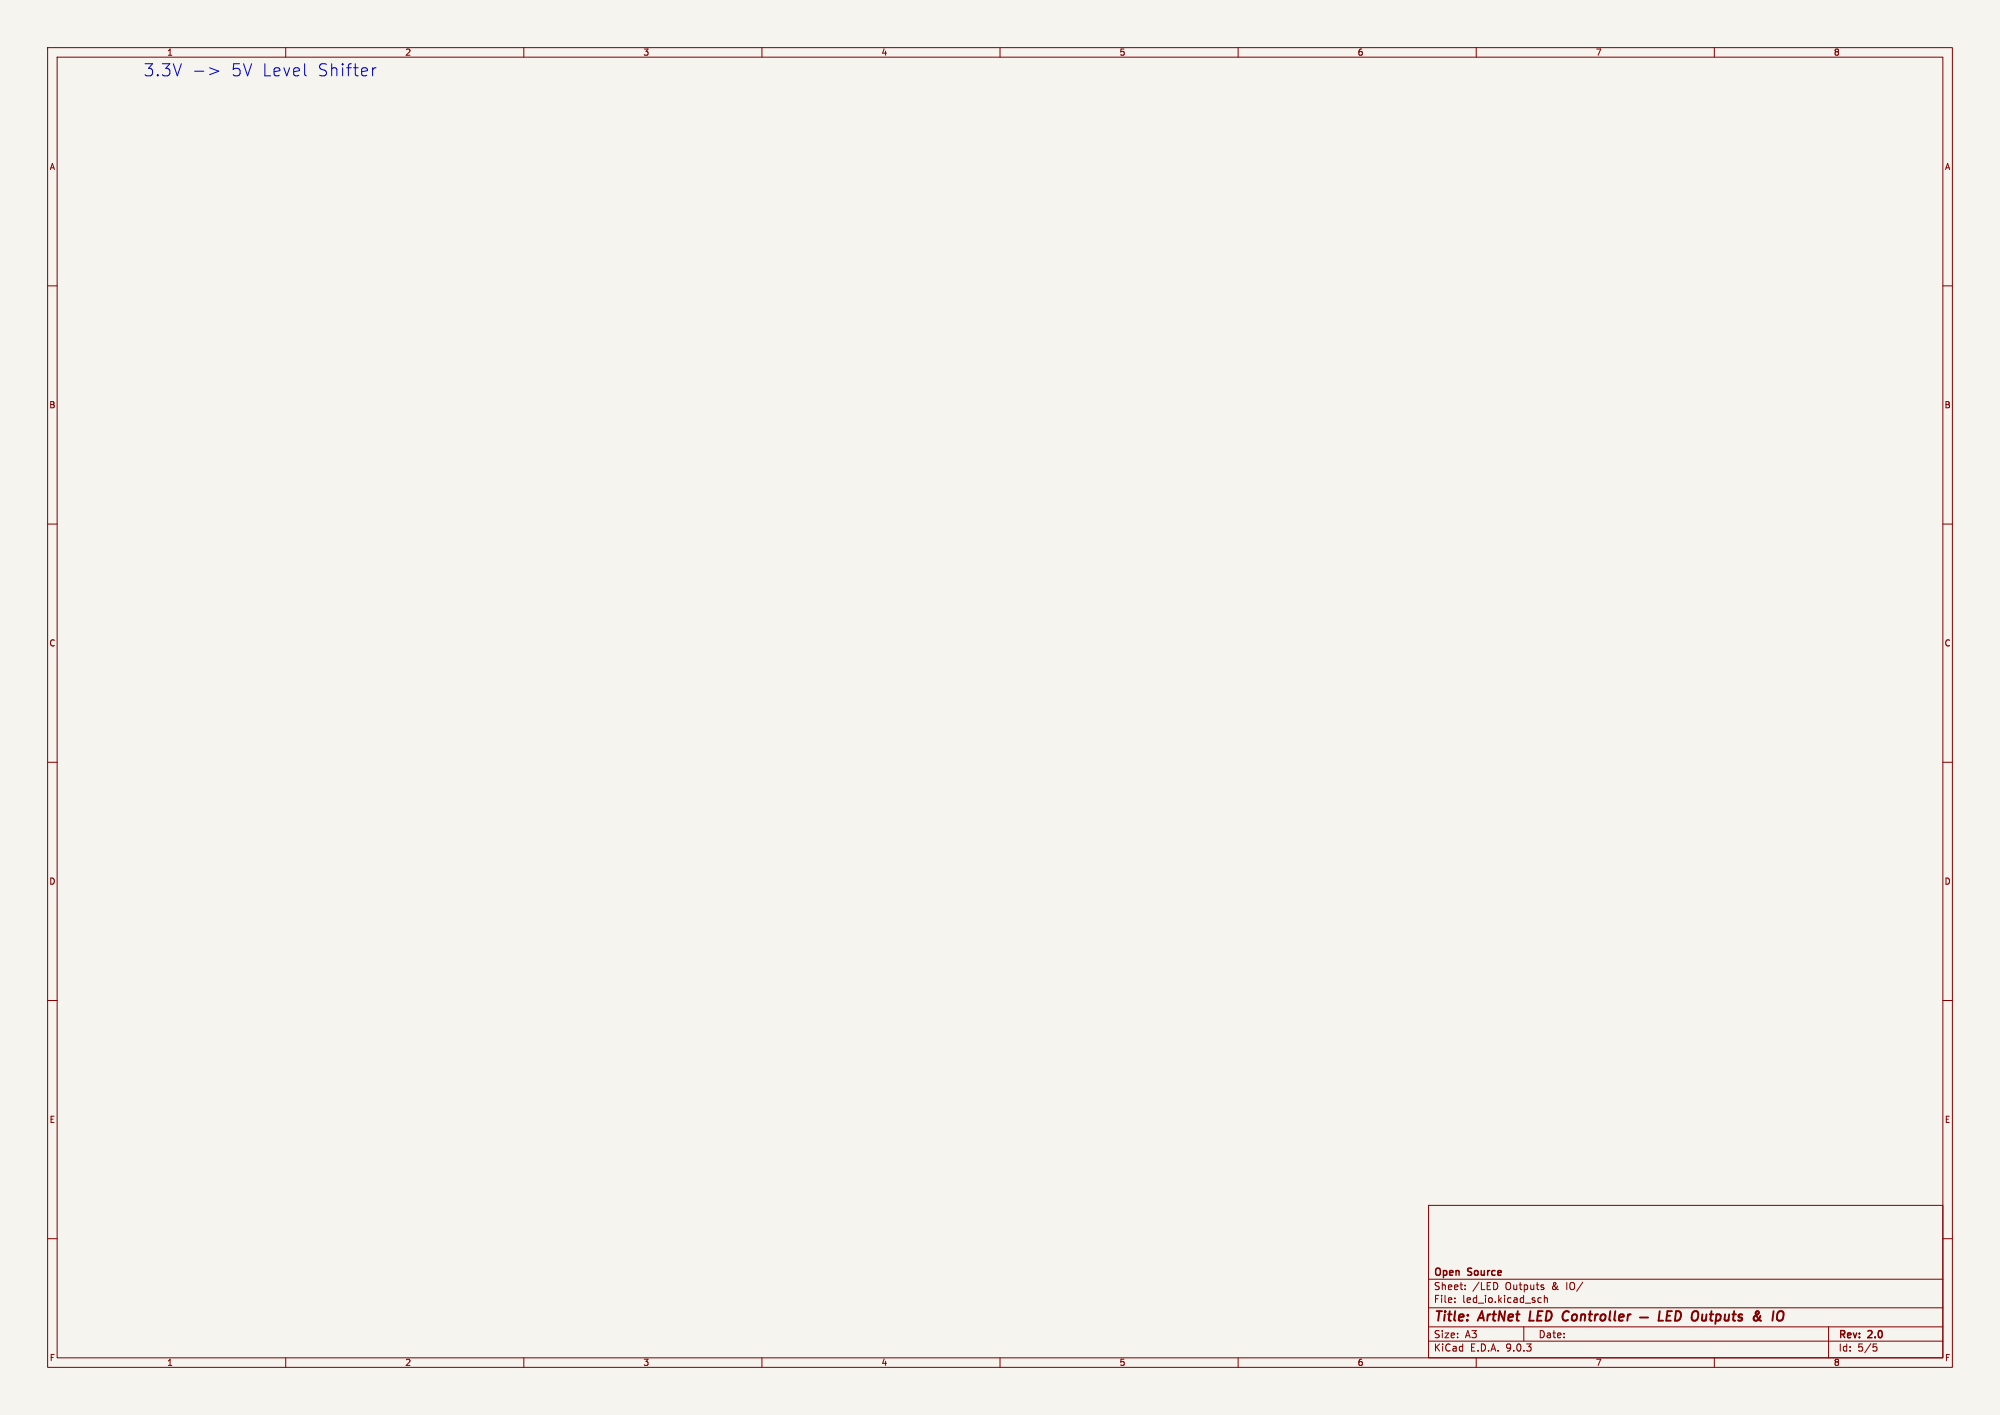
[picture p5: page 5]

Id: 5/5 Title: ArtNet LED Controller þÿ LED Outputs & IO

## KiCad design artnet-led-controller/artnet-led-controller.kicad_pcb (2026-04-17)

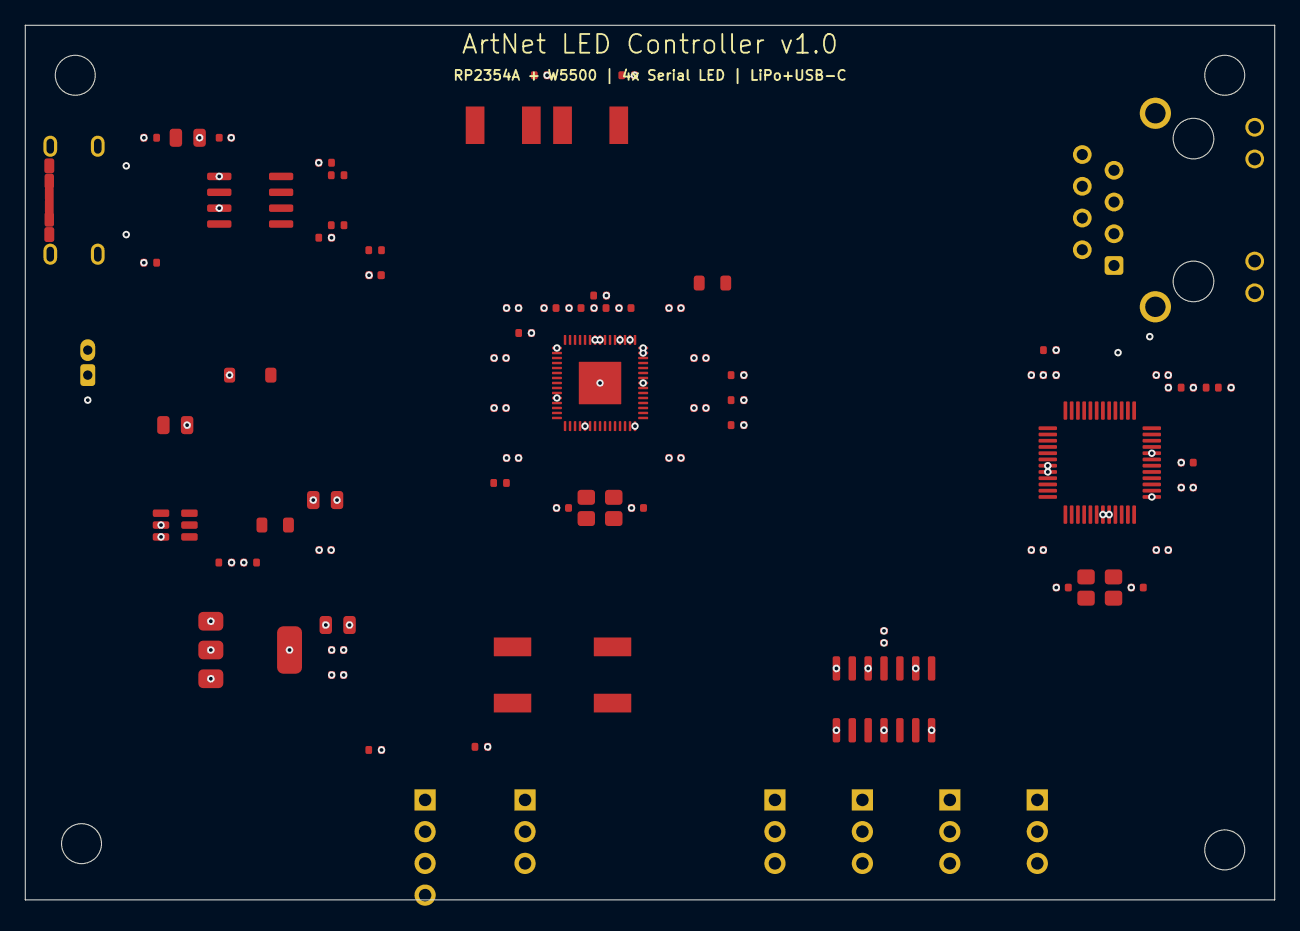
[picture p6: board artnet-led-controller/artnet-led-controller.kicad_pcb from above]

Board: 4 copper layers, 100.0 x 70.0 mm, 84 parts (0 on the bottom side), 52 nets, no tracks yet.

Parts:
C2, C3: 12pF; C_0402_1005Metric
C4, C8, C32, C35, C37, C38, C39, C40, C41, C42, C43, C44, C45, C47, C48, C49, C50, C52: 100nF; C_0402_1005Metric
C5, C6: 18pF; C_0402_1005Metric
C7, C9, C10, C46, C51: 4.7uF; C_0402_1005Metric
C31, C33, C34, C36: 10uF; C_0805_2012Metric
D1: SS14; D_SOD-123
D2: LED_GREEN; LED_0402_1005Metric
H1, H2, H3, H4: MountingHole; MountingHole_3.2mm_M3
J1: USB4125-GF-A; USB_C_Receptacle_GCT_USB4125-xx-x_6P_TopMnt_Horizontal
J2: HR911105A; RJ45_Hanrun_HR911105A_Horizontal
J3: VBAT JST-PH-2; JST_PH_B2B-PH-K_1x02_P2.00mm_Vertical
J5: LED_OUT_1; PinHeader_1x03_P2.54mm_Vertical
J6: LED_OUT_2; PinHeader_1x03_P2.54mm_Vertical
J7: LED_OUT_3; PinHeader_1x03_P2.54mm_Vertical
J8: LED_OUT_4; PinHeader_1x03_P2.54mm_Vertical
J9: OLED_SSD1306; PinHeader_1x04_P2.54mm_Vertical
J10: SWD_DEBUG; PinHeader_1x03_P2.54mm_Vertical
L1: 22uH; L_0805_2012Metric
L2: 3.3uH; L_0805_2012Metric
R1: 750k; R_0402_1005Metric
R2: 100k; R_0402_1005Metric
R3: 2k; R_0402_1005Metric
R4, R5: 5.1k; R_0402_1005Metric
R6: 330; R_0402_1005Metric
R7, R8, R14, R15, R16, R21, R22: 10k; R_0402_1005Metric
R9, R10: 27; R_0402_1005Metric
R11, R12, R13: 12.4k; R_0402_1005Metric
R17, R18: 49.9; R_0402_1005Metric
R19, R20: 4.7k; R_0402_1005Metric
R23: 33; R_0402_1005Metric
R24: 1k; R_0402_1005Metric
SW1, SW2, SW3, SW4: SW_Push; SW_Push_1P1T_NO_CK_KSC7xxJ
U1: RP2354A; QFN-60-1EP_7x7mm_P0.4mm_EP3.4x3.4mm
U3: W5500; LQFP-48_7x7mm_P0.5mm
U4: SN74AHCT125; SOIC-14_3.9x8.7mm_P1.27mm
U5: TP4056; SOIC-8_3.9x4.9mm_P1.27mm
U6: MT3608; SOT-23-6
U7: AMS1117-3.3; SOT-223-3_TabPin2
Y1: 12MHz; Crystal_SMD_3225-4Pin_3.2x2.5mm
Y2: 25MHz; Crystal_SMD_3225-4Pin_3.2x2.5mm

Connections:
BTN1: R21.1, SW1.1, U1.34
BTN2: R22.1, SW2.1, U1.35
CHRG_STAT: D2.2, R6.2, R7.1, U5.6
ETH_CT1: J2.8, R17.1
ETH_CT2: J2.9, R18.1
ETH_TXN: J2.12, U3.12
ETH_TXP: J2.11, U3.11
GND: C2.1, C3.1, C4.1, C5.1, C6.1, C7.1, C8.1, C9.1, C10.1, C31.2, C32.2, C33.2, C34.2, C35.2, C36.2, C37.2, C38.2, C39.2, C40.2, C41.2, C42.2, C43.2, C44.2, C45.2, C46.2, C47.2, C48.2, C49.2, C50.2, C51.2, C52.2, D2.1, J1.A12, J1.B12, J2.4, J2.5, J3.2, J5.1, J6.1, J7.1, J8.1, J9.2, J10.3, R2.1, R3.1, R4.1, R5.1, R11.1, R12.1, SW1.2, SW2.2, SW3.2, SW4.2, U1.47, U1.61, U3.8, U3.32, U4.1, U4.4, U4.7, U4.9, U4.12, U5.1, U5.3, U6.2, U7.1
I2C_SCL: J9.3, R19.1, U1.8
I2C_SDA: J9.4, R20.1, U1.7
LED1_DATA_3V3: U1.2, U4.2
LED1_DATA_5V: J5.2, U4.3
LED2_DATA_3V3: U1.3, U4.5
LED2_DATA_5V: J6.2, U4.6
LED3_DATA_3V3: U1.4, U4.10
LED3_DATA_5V: J7.2, U4.8
LED4_DATA_3V3: U1.5, U4.13
LED4_DATA_5V: J8.2, U4.11
MT3608_FB: R1.1, R2.2, U6.4
MT3608_SW: L1.2, U6.5
RP_RUN: R8.1, SW3.1, U1.26
RP_XIN: C2.2, U1.21, Y1.1
RP_XOUT: C3.2, U1.22, Y1.2
SPI_CS: R15.1, U1.28, U3.24
SPI_MISO: R14.1, U1.27, U3.21
SPI_MOSI: U1.31, U3.22
SPI_SCK: U1.29, U3.23
SWCLK: J10.1, U1.24
SWDIO: J10.2, U1.25
TP4056_PROG: R3.2, U5.2
USB_BOOT: R24.2, U1.60
USB_BOOT_SW: R24.1, SW4.1
USB_CC1: J1.A5, R4.2
USB_CC2: J1.B5, R5.2
USB_DM_MCU: R10.1, U1.51
USB_DP_MCU: R9.1, U1.52
VBAT: C33.1, J3.1, U5.5, U6.1
VBOOST_RAW: D1.2, L1.1
VCC3V3: C36.1, C37.1, C38.1, C39.1, C40.1, C41.1, C42.1, C43.1, C44.1, C45.1, C46.1, C47.1, C48.1, C49.1, C50.1, C51.1, J2.7, J9.1, R7.2, R8.2, R13.2, R14.2, R15.2, R16.2, R17.2, R18.2, R19.2, R20.2, R21.2, R22.2, R23.2, U1.1, U1.11, U1.20, U1.30, U1.38, U1.44, U1.45, U1.49, U1.53, U1.54, U3.7, U3.19, U3.20, U3.25, U7.2
VCC5V: C34.1, C35.1, C52.1, D1.1, J5.3, J6.3, J7.3, J8.3, R1.2, U4.14, U6.3, U7.3
VREG_1V1: C7.2, C9.2, C10.2, L2.1, U1.6, U1.23, U1.39, U1.50
VREG_AVDD: C8.2, R23.1, U1.46
VREG_LX: L2.2, U1.48
VUSB: C31.1, C32.1, U5.4, U5.8
W5_VDD: C4.2, U3.26
W5_XTAL1: C5.2, U3.15, Y2.1
W5_XTAL2: C6.2, U3.16, Y2.2
W5500_EXRES0: R11.2, U3.10
W5500_EXRES1: R13.1, U3.5, U3.6
W5500_INT: U1.32, U3.27
W5500_RCLK: R12.2, U3.9
W5500_RST: R16.1, U1.33, U3.28

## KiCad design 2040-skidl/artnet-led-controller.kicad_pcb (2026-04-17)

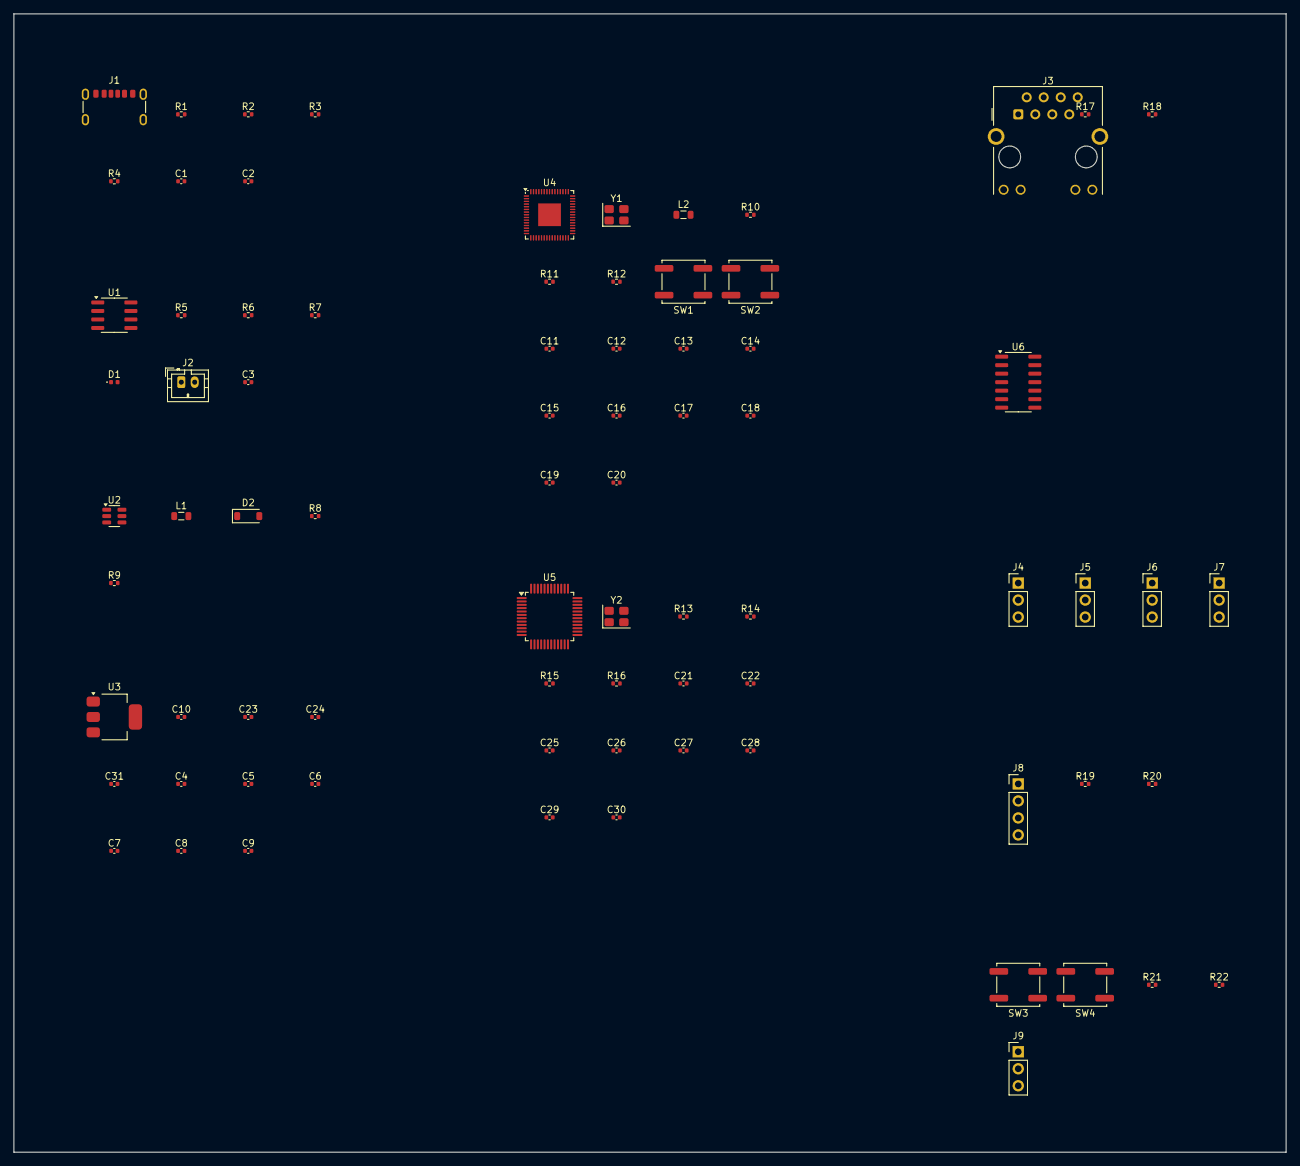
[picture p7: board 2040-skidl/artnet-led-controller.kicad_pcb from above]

Board: 4 copper layers, 190.0 x 170.0 mm, 78 parts (0 on the bottom side), 51 nets, no tracks yet.

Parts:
C1, C3, C4, C6: 10uF; C_0402_1005Metric
C2, C5, C7, C8, C14, C15, C16, C17, C18, C19, C20, C21, C25, C26, C27, C28, C29, C31: 100nF; C_0402_1005Metric
C9, C10: 12pF; C_0402_1005Metric
C11, C12, C13, C22, C30: 4.7uF; C_0402_1005Metric
C23, C24: 18pF; C_0402_1005Metric
D1: GREEN; LED_0402_1005Metric
D2: SS14; D_SOD-123
J1: USB4125-GF-A; USB_C_Receptacle_GCT_USB4125-xx-x_6P_TopMnt_Horizontal
J2: JST-PH-2; JST_PH_B2B-PH-K_1x02_P2.00mm_Vertical
J3: HR911105A; RJ45_Hanrun_HR911105A_Horizontal
J4: LED_OUT_1; PinHeader_1x03_P2.54mm_Vertical
J5: LED_OUT_2; PinHeader_1x03_P2.54mm_Vertical
J6: LED_OUT_3; PinHeader_1x03_P2.54mm_Vertical
J7: LED_OUT_4; PinHeader_1x03_P2.54mm_Vertical
J8: OLED_SSD1306; PinHeader_1x04_P2.54mm_Vertical
J9: SWD_DEBUG; PinHeader_1x03_P2.54mm_Vertical
L1: 22uH; L_0805_2012Metric
L2: 3.3uH; L_0805_2012Metric
R1, R2: 27; R_0402_1005Metric
R3, R4: 5.1k; R_0402_1005Metric
R5: 2k; R_0402_1005Metric
R6: 330; R_0402_1005Metric
R7, R11, R14, R15, R16, R21, R22: 10k; R_0402_1005Metric
R8: 750k; R_0402_1005Metric
R9: 100k; R_0402_1005Metric
R10: 33; R_0402_1005Metric
R12: 1k; R_0402_1005Metric
R13: 12.4k; R_0402_1005Metric
R17, R18: 49.9; R_0402_1005Metric
R19, R20: 4.7k; R_0402_1005Metric
SW1: RESET; SW_Push_1P1T_NO_CK_KSC7xxJ
SW2: BOOTSEL; SW_Push_1P1T_NO_CK_KSC7xxJ
SW3: BTN1; SW_Push_1P1T_NO_CK_KSC7xxJ
SW4: BTN2; SW_Push_1P1T_NO_CK_KSC7xxJ
U1: TP4056; SOIC-8_3.9x4.9mm_P1.27mm
U2: MT3608; SOT-23-6
U3: AMS1117-3.3; SOT-223-3_TabPin2
U4: RP2354A; QFN-60-1EP_7x7mm_P0.4mm_EP3.4x3.4mm
U5: W5500; LQFP-48_7x7mm_P0.5mm
U6: SN74AHCT125; SOIC-14_3.9x8.7mm_P1.27mm
Y1: 12MHz; Crystal_SMD_3225-4Pin_3.2x2.5mm
Y2: 25MHz; Crystal_SMD_3225-4Pin_3.2x2.5mm

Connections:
BOOT_SW: R12.2, SW2.1
BTN1: R21.2, SW3.1, U4.34
BTN2: R22.2, SW4.1, U4.35
CC1: J1.A5, R3.1
CC2: J1.B5, R4.1
CHRG_STAT: D1.1, R6.1, R7.2, U1.7
CT1: J3.4, R17.2
CT2: J3.5, R18.2
ETH_RXN: J3.6, U5.5
ETH_RXP: J3.3, U5.6
ETH_TXN: J3.2, U5.1
ETH_TXP: J3.1, U5.2
EXRES1: R13.1, U5.10
FB: R8.2, R9.1, U2.3
GND: C1.2, C2.2, C3.2, C4.2, C5.2, C6.2, C7.2, C8.2, C9.2, C10.2, C11.2, C12.2, C13.2, C14.2, C15.2, C16.2, C17.2, C18.2, C19.2, C20.2, C21.2, C22.2, C23.2, C24.2, C25.2, C26.2, C27.2, C28.2, C29.2, C30.2, C31.2, D1.2, J1.A12, J1.B12, J2.2, J3.SH, J4.1, J5.1, J6.1, J7.1, J8.2, J9.3, R3.2, R4.2, R5.2, R6.2, R9.2, R13.2, SW1.2, SW2.2, SW3.2, SW4.2, U1.1, U1.3, U2.2, U3.1, U4.47, U4.61, U5.3, U5.9, U5.14, U5.16, U5.19, U5.29, U5.43, U5.44, U5.45, U5.48, U6.1, U6.4, U6.7, U6.9, U6.12
I2C_SCL: J8.3, R19.2, U4.8
I2C_SDA: J8.4, R20.2, U4.7
LED1_5V: J4.2, U6.3
LED1_DATA: U4.2, U6.2
LED2_5V: J5.2, U6.6
LED2_DATA: U4.3, U6.5
LED3_5V: J6.2, U6.8
LED3_DATA: U4.4, U6.10
LED4_5V: J7.2, U6.11
LED4_DATA: U4.5, U6.13
PROG: R5.1, U1.2
RUN: R11.2, SW1.1, U4.26
SPI_CS: R15.2, U4.28, U5.32
SPI_MISO: R14.2, U4.27, U5.34
SPI_MOSI: U4.31, U5.35
SPI_SCK: U4.29, U5.33
SW: L1.1, U2.1
SWCLK: J9.1, U4.24
SWDIO: J9.2, U4.25
USB_BOOT: R12.1, U4.60
USB_DM_MCU: R2.2, U4.51
USB_DP_MCU: R1.2, U4.52
VBAT: C3.1, J2.1, U1.5, U2.4, U2.5
VBOOST_RAW: D2.1, L1.2
VCC3V3: C6.1, C7.1, C8.1, C15.1, C16.1, C17.1, C18.1, C19.1, C20.1, C21.1, C22.1, C26.1, C27.1, C28.1, C29.1, C30.1, J8.1, R7.1, R10.1, R11.1, R14.1, R15.1, R16.1, R17.1, R18.1, R19.1, R20.1, R21.1, R22.1, U3.2, U4.1, U4.11, U4.20, U4.30, U4.38, U4.44, U4.45, U4.49, U4.53, U4.54, U5.4, U5.8, U5.11, U5.15, U5.17, U5.21
VCC5V: C4.1, C5.1, C31.1, D2.2, J4.3, J5.3, J6.3, J7.3, R8.1, U3.3, U6.14
VREG_1V1: C11.1, C12.1, C13.1, L2.2, U4.6, U4.23, U4.39, U4.50
VREG_AVDD: C14.1, R10.2, U4.46
VREG_LX: L2.1, U4.48
VUSB: C1.1, C2.1, J1.A9, J1.B9, U1.4, U1.8
W5_VDD: C25.1, U5.22, U5.28
W5500_INT: U4.32, U5.36
W5500_RST: R16.2, U4.33, U5.37
XIN: C9.1, U4.21, Y1.1
XOUT: C10.1, U4.22, Y1.2
XTAL1: C23.1, U5.30, Y2.1

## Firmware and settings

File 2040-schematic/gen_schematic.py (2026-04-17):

#!/usr/bin/env python3
"""
ArtNet LED Controller — Multi-sheet KiCad 9 Schematic Generator
Generates a root .kicad_sch with hierarchical sub-sheets for readability.
Exports netlist.json for downstream PCB layout tools.

Sheets:
  1. Root        — title block, power flags, sheet instances
  2. power.kicad_sch   — USB-C, TP4056, MT3608, AMS1117, battery
  3. mcu.kicad_sch     — RP2354A, crystal, buttons, USB resistors, decoupling
  4. ethernet.kicad_sch — W5500, RJ45, crystal, SPI/reset pullups
  5. led_io.kicad_sch  — 74AHCT125, LED connectors, OLED, user buttons, SWD
"""

import uuid, json
from pathlib import Path

DIR = Path(__file__).resolve().parent
PROJECT = "artnet-led-controller"

# ---------------------------------------------------------------------------
# Helpers
# ---------------------------------------------------------------------------
def u():
    return str(uuid.uuid4())

_pwr_n = 0
def pwr_ref():
    global _pwr_n; _pwr_n += 1
    return f"#PWR{_pwr_n:03d}"

# S-expression primitives
def wire(x1, y1, x2, y2):
    return (f'  (wire (pts (xy {x1:.3f} {y1:.3f}) (xy {x2:.3f} {y2:.3f}))\n'
            f'    (stroke (width 0) (type default)) (uuid "{u()}"))')

def no_connect(x, y):
    return f'  (no_connect (at {x:.3f} {y:.3f}) (uuid "{u()}"))'

def net_label(name, x, y, angle=0):
    return (f'  (label "{name}" (at {x:.3f} {y:.3f} {angle}) (fields_autoplaced)\n'
            f'    (effects (font (size 1.27 1.27)) (justify left))\n'
            f'    (uuid "{u()}")\n'
            f'    (property "Intersheet References" "" (at {x:.3f} {y:.3f} 0)\n'
            f'      (effects (font (size 1.27 1.27)) (hide yes))))')

def global_label(name, x, y, angle=0, shape="bidirectional"):
    """Global label for inter-sheet connections."""
    return (f'  (global_label "{name}" (shape {shape}) (at {x:.3f} {y:.3f} {angle})\n'
            f'    (effects (font (size 1.27 1.27)) (justify left))\n'
            f'    (uuid "{u()}")\n'
            f'    (property "Intersheet References" "" (at {x:.3f} {y:.3f} 0)\n'
            f'      (effects (font (size 1.27 1.27)) (hide yes))))')

def power_sym(net, x, y, angle=0):
    ref = pwr_ref()
    ya = y + 2.54 if angle == 0 else y
    yv = y - 2.54 if angle == 0 else y + 2.54
    return (f'  (symbol (lib_id "power:{net}") (at {x:.3f} {y:.3f} {angle})(unit 1)(in_bom yes)(on_board yes)\n'
            f'    (uuid "{u()}")\n'
            f'    (property "Reference" "{ref}" (at {x:.3f} {ya:.3f} 0)(effects (font (size 1.27 1.27))(hide yes)))\n'
            f'    (property "Value" "{net}" (at {x:.3f} {yv:.3f} 0)(effects (font (size 1.27 1.27))))\n'
            f'    (property "Footprint" "" (at {x:.3f} {y:.3f} 0)(effects (font (size 1.27 1.27))(hide yes)))\n'
            f'    (property "Datasheet" "" (at {x:.3f} {y:.3f} 0)(effects (font (size 1.27 1.27))(hide yes)))\n'
            f'    (instances (project "{PROJECT}" (path "/{u()}" (reference "{ref}")(unit 1)))))')

def comp(lib_id, ref, value, fp, x, y, lcsc="", angle=0):
    lines = [
        f'  (symbol (lib_id "{lib_id}") (at {x:.3f} {y:.3f} {angle})(unit 1)(in_bom yes)(on_board yes)',
        f'    (uuid "{u()}")',
        f'    (property "Reference" "{ref}" (at {x:.3f} {y - 3.81:.3f} 0)(effects (font (size 1.27 1.27))))',
        f'    (property "Value" "{value}" (at {x:.3f} {y + 3.81:.3f} 0)(effects (font (size 1.27 1.27))))',
        f'    (property "Footprint" "{fp}" (at {x:.3f} {y:.3f} 0)(effects (font (size 1.27 1.27))(hide yes)))',
        f'    (property "Datasheet" "" (at {x:.3f} {y:.3f} 0)(effects (font (size 1.27 1.27))(hide yes)))',
    ]
    if lcsc:
        lines += [
            f'    (property "LCSC" "{lcsc}" (at {x:.3f} {y:.3f} 0)(effects (font (size 1.27 1.27))(hide yes)))',
        ]
    lines += [
        f'    (instances (project "{PROJECT}" (path "/{u()}" (reference "{ref}")(unit 1))))',
        f'  )',
    ]
    return '\n'.join(lines)

def text_note(text, x, y):
    return (f'  (text "{text}" (at {x:.3f} {y:.3f} 0)\n'
            f'    (effects (font (size 2.54 2.54)) (justify left)))')


# ---------------------------------------------------------------------------
# Symbol library definitions (inline)
# All custom symbols are defined here; standard R/C/L use KiCad builtins.
# ---------------------------------------------------------------------------
PIN_LEN = 2.54
_sym_pin_defs = {}  # for netlist extraction

def build_symbol(sym_name, body, pins, pin_names_offset=1.016):
    _sym_pin_defs[sym_name] = (body, pins)
    x1, y1, x2, y2 = body
    endpoints = {}
    pin_lines = []
    for side, off, name, num, ptype in pins:
        if ptype == 'bidir':
            ptype = 'bidirectional'
        if side == 'L':
            px, py, ang = x1 - PIN_LEN, off, 0
        elif side == 'R':
            px, py, ang = x2 + PIN_LEN, off, 180
        elif side == 'T':
            px, py, ang = off, y1 - PIN_LEN, 270
        else:
            px, py, ang = off, y2 + PIN_LEN, 90
        endpoints[name] = (px, py)
        pin_lines.append(
            f'      (pin {ptype} line (at {px:.3f} {py:.3f} {ang}) (length {PIN_LEN})\n'
            f'        (name "{name}" (effects (font (size 1.016 1.016))))\n'
            f'        (number "{num}" (effects (font (size 1.016 1.016)))))'
        )
    body_rect = (f'    (symbol "{sym_name}_0_1"\n'
                 f'      (rectangle (start {x1:.3f} {y1:.3f}) (end {x2:.3f} {y2:.3f})\n'
                 f'        (stroke (width 0) (type default)) (fill (type background))))\n')
    pin_block = (f'    (symbol "{sym_name}_1_1"\n' +
                 '\n'.join(pin_lines) + '\n    )\n')
    sym_text = (f'    (symbol "{sym_name}"\n'
                f'      (pin_names (offset {pin_names_offset:.3f}))\n'
                f'      (in_bom yes) (on_board yes)\n'
                f'      (property "Reference" "U" (at 0 {y1 - 3.81:.3f} 0)\n'
                f'        (effects (font (size 1.27 1.27))))\n'
                f'      (property "Value" "{sym_name}" (at 0 {y2 + 3.81:.3f} 0)\n'
                f'        (effects (font (size 1.27 1.27))))\n'
                f'      (property "Footprint" "" (at 0 0 0)\n'
                f'        (effects (font (size 1.27 1.27)) (hide yes)))\n'
                f'      (property "Datasheet" "" (at 0 0 0)\n'
                f'        (effects (font (size 1.27 1.27)) (hide yes)))\n'
                + body_rect + pin_block + '    )\n')
    return sym_text, endpoints


# ── Build all symbol definitions ────────────────────────────────────────────
lib_symbols = []
all_endpoints = {}

# RP2354A (QFN-60)
S = 2.54
rp_body = (-20.32, -31.75, 20.32, 31.75)
def lpin(i, name, num, ptype='bidir'): return ('L', -25.4 + i * S, name, num, ptype)
def rpin(i, name, num, ptype='bidir'): return ('R', -27.94 + i * S, name, num, ptype)
def tpin(i, name, num, ptype='power_in'): return ('T', -5.08 + i * S, name, num, ptype)
def bpin(i, name, num, ptype='power_in'): return ('B', -8.89 + i * S, name, num, ptype)
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

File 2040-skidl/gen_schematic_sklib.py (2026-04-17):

from collections import defaultdict
from skidl import Pin, Part, Alias, SchLib, SKIDL, TEMPLATE

from skidl.pin import pin_types

SKIDL_lib_version = '0.0.1'

gen_schematic = SchLib(tool=SKIDL).add_parts(*[
        Part(**{ 'name':'R', 'dest':TEMPLATE, 'tool':SKIDL, 'aliases':Alias({'R'}), 'ref_prefix':'R', 'fplist':[''], 'footprint':'Resistor_SMD:R_0402_1005Metric', 'keywords':'R res resistor', 'description':'Resistor', 'datasheet':'~', 'pins':[
            Pin(num='1',name='~',func=pin_types.PASSIVE,unit=1),
            Pin(num='2',name='~',func=pin_types.PASSIVE,unit=1)], 'unit_defs':[] }),
        Part(**{ 'name':'USB_C_Receptacle', 'dest':TEMPLATE, 'tool':SKIDL, 'aliases':Alias({'USB_C_Receptacle'}), 'ref_prefix':'J', 'fplist':[''], 'footprint':'Connector_USB:USB_C_Receptacle_GCT_USB4125-xx-x_6P_TopMnt_Horizontal', 'keywords':'usb universal serial bus type-C full-featured', 'description':'USB Full-Featured Type-C Receptacle connector', 'datasheet':'https://www.usb.org/sites/default/files/documents/usb_type-c.zip', 'pins':[
            Pin(num='S1',name='SHIELD',func=pin_types.PASSIVE,unit=1),
            Pin(num='A1',name='GND',func=pin_types.PASSIVE,unit=1),
            Pin(num='A12',name='GND',func=pin_types.PASSIVE,unit=1),
            Pin(num='B1',name='GND',func=pin_types.PASSIVE,unit=1),
            Pin(num='B12',name='GND',func=pin_types.PASSIVE,unit=1),
            Pin(num='A4',name='VBUS',func=pin_types.PASSIVE,unit=1),
            Pin(num='A9',name='VBUS',func=pin_types.PASSIVE,unit=1),
            Pin(num='B4',name='VBUS',func=pin_types.PASSIVE,unit=1),
            Pin(num='B9',name='VBUS',func=pin_types.PASSIVE,unit=1),
            Pin(num='A5',name='CC1',func=pin_types.BIDIR,unit=1),
            Pin(num='B5',name='CC2',func=pin_types.BIDIR,unit=1),
            Pin(num='A7',name='D-',func=pin_types.BIDIR,unit=1),
            Pin(num='B7',name='D-',func=pin_types.BIDIR,unit=1),
            Pin(num='A6',name='D+',func=pin_types.BIDIR,unit=1),
            Pin(num='B6',name='D+',func=pin_types.BIDIR,unit=1),
            Pin(num='B10',name='RX1-',func=pin_types.BIDIR,unit=1),
            Pin(num='B11',name='RX1+',func=pin_types.BIDIR,unit=1),
            Pin(num='A3',name='TX1-',func=pin_types.BIDIR,unit=1),
            Pin(num='A2',name='TX1+',func=pin_types.BIDIR,unit=1),
            Pin(num='A10',name='RX2-',func=pin_types.BIDIR,unit=1),
            Pin(num='A11',name='RX2+',func=pin_types.BIDIR,unit=1),
            Pin(num='B3',name='TX2-',func=pin_types.BIDIR,unit=1),
            Pin(num='B2',name='TX2+',func=pin_types.BIDIR,unit=1),
            Pin(num='A8',name='SBU1',func=pin_types.BIDIR,unit=1),
            Pin(num='B8',name='SBU2',func=pin_types.BIDIR,unit=1)], 'unit_defs':[] }),
        Part(**{ 'name':'C', 'dest':TEMPLATE, 'tool':SKIDL, 'aliases':Alias({'C'}), 'ref_prefix':'C', 'fplist':[''], 'footprint':'Capacitor_SMD:C_0402_1005Metric', 'keywords':'cap capacitor', 'description':'Unpolarized capacitor', 'datasheet':'~', 'pins':[
            Pin(num='1',name='~',func=pin_types.PASSIVE,unit=1),
            Pin(num='2',name='~',func=pin_types.PASSIVE,unit=1)], 'unit_defs':[] }),
        Part(**{ 'name':'TP4056-42-ESOP8', 'dest':TEMPLATE, 'tool':SKIDL, 'aliases':Alias({'TP4056-42-ESOP8'}), 'ref_prefix':'U', 'fplist':['Package_SO:SOIC-8-1EP_3.9x4.9mm_P1.27mm_EP2.41x3.3mm_ThermalVias'], 'footprint':'Package_SO:SOIC-8_3.9x4.9mm_P1.27mm', 'keywords':'lithium-ion lithium-polymer Li-Poly', 'description':'1A Standalone Linear Li-ion/LiPo single-cell battery charger, 4.2V Â±1% charge voltage, VCC = 4.0..8.0V, SOIC-8 (SOP-8)', 'datasheet':'https://www.lcsc.com/datasheet/lcsc_datasheet_2410121619_TOPPOWER-Nanjing-Extension-Microelectronics-TP4056-42-ESOP8_C16581.pdf', 'pins':[
            Pin(num='8',name='CE',func=pin_types.INPUT,unit=1),
            Pin(num='7',name='~{CHRG}',func=pin_types.OPENCOLL,unit=1),
            Pin(num='6',name='~{STDBY}',func=pin_types.OPENCOLL,unit=1),
            Pin(num='9',name='EPAD',func=pin_types.PASSIVE,unit=1),
            Pin(num='4',name='V_{CC}',func=pin_types.PWRIN,unit=1),
            Pin(num='3',name='GND',func=pin_types.PWRIN,unit=1),
            Pin(num='5',name='BAT',func=pin_types.PWROUT,unit=1),
            Pin(num='1',name='TEMP',func=pin_types.INPUT,unit=1),
            Pin(num='2',name='PROG',func=pin_types.PASSIVE,unit=1)], 'unit_defs':[] }),
        Part(**{ 'name':'LED', 'dest':TEMPLATE, 'tool':SKIDL, 'aliases':Alias({'LED'}), 'ref_prefix':'D', 'fplist':[''], 'footprint':'LED_SMD:LED_0402_1005Metric', 'keywords':'LED diode', 'description':'Light emitting diode', 'datasheet':'~', 'pins':[
            Pin(num='1',name='K',func=pin_types.PASSIVE,unit=1),
            Pin(num='2',name='A',func=pin_types.PASSIVE,unit=1)], 'unit_defs':[] }),
        Part(**{ 'name':'Conn_01x02', 'dest':TEMPLATE, 'tool':SKIDL, 'aliases':Alias({'Conn_01x02'}), 'ref_prefix':'J', 'fplist':[''], 'footprint':'Connector_JST:JST_PH_B2B-PH-K_1x02_P2.00mm_Vertical', 'keywords':'connector', 'description':'Generic connector, single row, 01x02, script generated (kicad-library-utils/schlib/autogen/connector/)', 'datasheet':'~', 'pins':[
            Pin(num='1',name='Pin_1',func=pin_types.PASSIVE,unit=1),
            Pin(num='2',name='Pin_2',func=pin_types.PASSIVE,unit=1)], 'unit_defs':[] }),
        Part(**{ 'name':'MT3608', 'dest':TEMPLATE, 'tool':SKIDL, 'aliases':Alias({'MT3608'}), 'ref_prefix':'U', 'fplist':['Package_TO_SOT_SMD:SOT-23-6'], 'footprint':'Package_TO_SOT_SMD:SOT-23-6', 'keywords':'Step-Up Boost DC-DC Regulator Adjustable', 'description':'High Efficiency 1.2MHz 2A Step Up Converter, 2-24V Vin, 28V Vout, 4A current limit, 1.2MHz, SOT23-6', 'datasheet':'https://www.olimex.com/Products/Breadboarding/BB-PWR-3608/resources/MT3608.pdf', 'pins':[
            Pin(num='5',name='IN',func=pin_types.PWRIN,unit=1),
            Pin(num='4',name='EN',func=pin_types.INPUT,unit=1),
            Pin(num='2',name='GND',func=pin_types.PWRIN,unit=1),
            Pin(num='6',name='NC',func=pin_types.NOCONNECT,unit=1),
            Pin(num='1',name='SW',func=pin_types.PASSIVE,unit=1),
            Pin(num='3',name='FB',func=pin_types.INPUT,unit=1)], 'unit_defs':[] }),
        Part(**{ 'name':'L', 'dest':TEMPLATE, 'tool':SKIDL, 'aliases':Alias({'L'}), 'ref_prefix':'L', 'fplist':[''], 'footprint':'Inductor_SMD:L_0805_2012Metric', 'keywords':'inductor choke coil reactor magnetic', 'description':'Inductor', 'datasheet':'~', 'pins':[
            Pin(num='1',name='1',func=pin_types.PASSIVE,unit=1),
            Pin(num='2',name='2',func=pin_types.PASSIVE,unit=1)], 'unit_defs':[] }),
        Part(**{ 'name':'D_Schottky', 'dest':TEMPLATE, 'tool':SKIDL, 'aliases':Alias({'D_Schottky'}), 'ref_prefix':'D', 'fplist':[''], 'footprint':'Diode_SMD:D_SOD-123', 'keywords':'diode Schottky', 'description':'Schottky diode', 'datasheet':'~', 'pins':[
            Pin(num='1',name='K',func=pin_types.PASSIVE,unit=1),
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

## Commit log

2026-04-12 Initial KiCad 7 design: RP2040 ArtNet LED controller
    - RP2040 + W5500 Ethernet (ArtNet UDP/6454), 4x WS2812 serial outputs
    - SN74AHCT125 level shifter (3.3V→5V), 1024-pixel capable
    - TP4056 LiPo charger + MT3608 boost + AMS1117-3.3 LDO
    - USB-C input, JST-PH battery, SSD1306 OLED header
    - HR911105A RJ45 with integrated magnetics
    - 100x70mm 2-layer board, JLCPCB BOM with LCSC part numbers
    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
    [artnet-led-controller.kicad_pcb, artnet-led-controller.kicad_sch, jlcpcb-bom.csv]
2026-04-12 Add root README.md
    Full project overview: architecture, pin assignments, JLCPCB order
    instructions, firmware recommendations, and PCB completion steps.
2026-04-14 Redesign controller around RP2354A
    [artnet-led-controller.kicad_pcb, artnet-led-controller.kicad_sch, jlcpcb-bom.csv]
2026-04-14 Clean PCB DRC and rotate RJ45
    [artnet-led-controller.kicad_pcb]
2026-04-14 Add netlist extraction and PCB pad net assignment
    gen_schematic.py now exports netlist.json mapping each ref to its
    pad-to-net assignments. gen_pcb.py loads this and injects (net N "name")
    into every pad block so the board is routable with freerouting.
    Also fixes pin_ep sign bug (cy+py -> cy-py) in schematic generator.
    [artnet-led-controller.kicad_pcb, artnet-led-controller.kicad_sch]
2026-04-15 Switch to 4-layer stackup with inner GND and VCC planes
    Move to a 4-layer JLCPCB stackup: F.Cu/B.Cu for signals, In1.Cu as
    VCC3V3 plane with a VCC5V island over the power-input column, In2.Cu
    as a solid GND plane. Reworked component placement (edge-facing jacks,
    courtyard-safe clusters) to improve routability.
    Freerouting CLI cannot exploit inner planes (its DSN parser rejects
    '(type power NET)'), so signal autorouting currently requires manual
    completion in KiCad's interactive router.
    [artnet-led-controller.kicad_pcb]
2026-04-17 Add SKiDL-based schematic generator for ArtNet LED controller
    Replaces hand-rolled KiCad S-expression generator with SKiDL, which
    produces a valid KiCad netlist (.net) directly from a Python circuit
    description. Covers full design: USB-C power, TP4056 charger, MT3608
    boost, AMS1117 LDO, RP2354A MCU, W5500 Ethernet, 74AHCT125 level
    shifter, 4x WS2812 outputs, OLED, buttons, and SWD debug header.
    [gen_schematic.py]
2026-04-17 Add subcircuit-based SKiDL schematic, PCB generator, and schematic sheets
    Refactor gen_schematic.py to use @subcircuit decorators for all functional
    blocks (USB, charger, boost, LDO, MCU, Ethernet, RJ45, LED outputs, OLED,
    buttons/SWD). Add gen_pcb.py with pcbnew API for real footprint placement
    in functional clusters with caps colocated near parent ICs. Add 2040-schematic
    directory with multi-sheet KiCad schematic. Update ref designators throughout.
    [artnet-led-controller.kicad_pcb, artnet-led-controller.kicad_sch, ethernet.kicad_sch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]
